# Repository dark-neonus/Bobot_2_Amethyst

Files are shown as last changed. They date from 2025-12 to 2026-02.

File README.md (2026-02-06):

# Bobot_2_Amethyst
Second robot from Bobot series of robots. A huge amount of things in this robot address problems of previous Bobot.

## Table of Contents

- [Features](#features)
  - [Mechanical](#mechanical)
    - [Handle](#handle)
    - [Back Buttons](#back-buttons)
    - [Power Switch](#power-switch)
    - [Screwdriver With Built In Case](#screwdriver-with-built-in-case)
    - [Access panel](#access-panel)
  - [Hardware](#hardware)
    - [Shortcut Components List](#shortcut-components-list)
    - [ESP32 Microcontroller](#esp32-microcontroller)
    - [2.42 Inch OLED I2C Display](#242-inch-oled-i2c-display)
    - [MAX98357A Audio Module](#max98357a-audio-module)
    - [Li-Po 3000mAh 3.7V Battery 1S2P](#li-po-3000mah-37v-battery-1s2p)
    - [BQ25895 Battery Management Module](#bq25895-battery-management-module)
    - [Button Board Based On MCP23017 I/O Expander](#button-board-based-on-mcp23017-io-expander)
    - [Touch Board Based On MPR121QR2 Touch Controller](#touch-board-based-on-mpr121qr2-touch-controller)
  - [Software](#software)
    - [Assets](#assets)
    - [Developer Tools](#developer-tools)
    - [Graphic Engine](#graphic-engine)

# Features 

## Mechanical

### Handle

#### Description

On the top there is the handle which is hidden in base.
It rotates out on bearings.
Rotation is locked by mechanism on top of base.

### Back Buttons

#### Description

On the back there are 9 buttons to interact with bobot.
They are with 3d printed tops with symbols representing purpose.

Buttons:
```
 _________________________________
|    Back    |  Up  |     UI      |
|____________|______|_____________|
|    Left    |  OK  |    Right    |
|____________|______|_____________|
|  Settings  | Down |    Debug    |
|____________|______|_____________|
```

### Power Switch

#### Description

At the bottom of left side of bobot(looking at their face) there is power switch, which is connect batteries to power regulation module.

### Screwdriver With Built In Case

#### Description

At the left side of bobot there is case with screwdriver which can unscrew all screws in bobot.
It is based on push latch mechanism, to be held inside of bobot.

### Access panel

#### Description

At the right side there is panel on 2 screws which give access to main microcontroller esp32 dev kit board. When this panel taken apart, esp32 can be fully removed from socket and access to micro sd is revealed.

## Hardware

### Shortcut Components List

| Component | Quantity| Description | Datasheet | Store |
|---|---|---|---|---|
|ESP32 unnamed DevKit board|1|Microcontroller|-|-|
|BQ25895 | 1 | power managment ic | [datasheet](https://www.ti.com/lit/ds/symlink/bq25895.pdf) | [store](https://www.aliexpress.com/item/1005008068013158.html) |
| MCP23017 | 1 | 16-Bit I/O Expander with Serial Interface(16 parallel pins to I2C) | [datasheet](https://ww1.microchip.com/downloads/en/devicedoc/20001952c.pdf) | [store](https://www.aliexpress.com/item/1005006974304942.html) |
| MPR121QR2  | 1 | 12 touch buttons driver with I2C interface | [datasheet](https://files.seeedstudio.com/wiki/Grove-I2C_Touch_Sensor/res/Freescale_Semiconductor;MPR121QR2.pdf) | [store](https://www.aliexpress.com/item/1005006944721047.html) |
| TL2285OA  | 9 | Push latch button without fixation | [datasheet](https://www.alldatasheet.com/html-pdf/437236/E-SWITCH/TL2285OA/385/1/TL2285OA.html) | [store](https://www.aliexpress.com/item/1005006775951751.html) |
| MAX98357A | 2 | Chip for audio output: DAC + amplifier in one chip | [datasheet](https://www.analog.com/media/en/technical-documentation/data-sheets/max98357a-max98357b.pdf) | [store](https://www.aliexpress.com/item/1005010444800168.html) |
| BMI160 | 1 | Sensor gyroscope + accelerometer 6DOF | - | [store](https://www.aliexpress.com/item/1005009421405155.html) |

| Component | Quantity| Store |
|---|---|---|
|Resistor 150Ω|1|[store](https://www.aliexpress.com/item/1005008789698065.html)|
|Resistor 4.7kΩ|6|[store](https://www.aliexpress.com/item/1005008789698065.html)|
|Resistor 5.1kΩ|1|[store](https://www.aliexpress.com/item/1005008789698065.html)|
|Resistor 10kΩ|18|[store](https://www.aliexpress.com/item/1005008789698065.html)|
|Resistor 33kΩ|1|[store](https://www.aliexpress.com/item/1005008789698065.html)|
|Resistor 75kΩ|1|[store](https://www.aliexpress.com/item/1005008789698065.html)|
|Capacitor 47nF|1|[store](https://www.aliexpress.com/item/1005010516436707.html)|
|Capacitor 100nF|2|[store](https://www.aliexpress.com/item/1005010516436707.html)|
|Capacitor 1uF|10|[store](https://www.aliexpress.com/item/1005010516436707.html)|
|Capacitor 4.7uF|1|[store](https://www.aliexpress.com/item/1005010516436707.html)|
|Capacitor 10uF|4|[store](https://www.aliexpress.com/item/1005010516436707.html)|
|Inductor 2.2uH|1|[store](https://www.aliexpress.com/item/1005001699576419.html)|
|Thermistor B3435 MF52D 10K|1|[store](https://www.aliexpress.com/item/1005006804356266.html)|

### ESP32 Microcontroller

#### Description

Main microcontroller will be unnamed clone of esp32 wroom dev kit with `30 pins`.
It will be placed in sockets on pcb on right side of bobot.

#### Links

[Overview](https://www.espboards.dev/esp32/esp32-30pin-devkit-generic/)

[Datasheet](https://documentation.espressif.com/esp32_datasheet_en.pdf)

[Technical Reference Manual](http://documentation.espressif.com/esp32_technical_reference_manual_en.pdf)

### 2.42 Inch OLED I2C Display

#### Description

There is 2.42 inch OLED display in front side of bobot.
Esp32 communicate with display using `i2c` protocol on
esp32 dedicated i2c pins. This display use SSD1309 driver.

#### Pinout

| Pin / Signal | Source / Connection | GPIO / Net | Description |
|---|---|---|---|
| SDA | ESP32 | GPIO21 | I²C data line (main I²C bus) |
| SCL | ESP32 | GPIO22 | I²C clock line (main I²C bus) |

#### Links

[General information](https://turkish.chenghaolcd.com/doc/44205281/2-42-oled-display-module-ic-i2c-spi-serial-with-ssd1309-controller.pdf)

### MAX98357A Audio Module

#### Description

Bobot uses two MAX98357A modules for stereo audio output. Each module integrates a DAC and Class D amplifier. One module is strapped for left channel, the other for right channel. The modules communicate with ESP32 via shared I2S bus.

#### Configurations

Hardware:

1. Left channel module: GAIN <mark>CONNECTION_TBD</mark> and <span style="text-decoration:overline">SD_MODE</span> strapped to VCC for left channel output
2. Right channel module: GAIN <mark>CONNECTION_TBD</mark> and <span style="text-decoration:overline">SD_MODE</span> strapped to GND for right channel output
3. Both modules share common I2S data and clock lines
4. 1 µF decoupling capacitor between VDD and GND for each module

Software:

1. Configure ESP32 I2S peripheral in stereo mode
2. Set sample rate to <mark>SAMPLE_RATE_TBD</mark> and bit depth to <mark>BIT_DEPTH_TBD</mark>

#### Pinout

| Pin / Signal | Connection | Net / GPIO | Description |
|---|---|---|---|
| LRC (LRCLK) | ESP32 | GPIO27 | I²S word select (left/right clock); shared between both modules. |
| BCLK | ESP32 | GPIO26 | I²S bit clock; shared between both modules. |
| DIN | ESP32 | GPIO25 | I²S serial data input; shared between both modules. |
| GAIN | Configured per module | — | Gain setting pin; sets output gain. |
| <span style="text-decoration:overline">SD_MODE</span> | Configured per module | — | Channel select: left or right. |
| VDD | 3.3V | 3.3V | Power supply (2.5-5.5V); 1 µF decoupling to GND. |
| GND | Ground | GND | Ground. |

#### Links

[Datasheet](https://www.analog.com/media/en/technical-documentation/data-sheets/max98357a-max98357b.pdf)

### Li-Po 3000mAh 3.7V Battery 1S2P

#### Description

There are two parallely connecteed li-po battery in bobot, which in total give 6000mAh battery capacity.

#### Links

[Buy](https://prom.ua/ua/p2843472521-litij-polimernyj-akkumulyator.html)

### BQ25895 Battery Management Module

#### Description

Bobot have power management module, which will consist of: 
- `BQ25895` I2C Controlled Single Cell 5-A Fast Charger with MaxChargeTM for High Input
Voltage and Adjustable Voltage 3.1-A Boost Operation
- Thermistor as BQ25895 requires placed onto battery with
  RTHcold = 27 kΩ at 0 °C
  and RTHhot = 4.9 kΩ at 45 °C values
- Led to indicate charge status
- Connection to esp32 I2C bus and INT pin support

And will do:
- Active conversation with Esp32 with transfering measurements of voltages and current(battery monitor feature)

#### Configurations

Hardware:

1. CE pin tied to GND to enable charging
2. Using resistors RT1=5.1 kΩ and RT2=33 kΩ to make BQ25895 read thermistor values correct
3. Led going from SYS to STAT through 2.2kΩ resistor
4. Connecting ILIM pin to GND through Rilim=150 Ω resistor. Calculated using formula from datasheet at section 8.2.12. 150 Ω resistor limit input current to ~2.6A.
5. OTG pin connected to GND to disable boost mode activation

Software:

1. Set register CONV_RATE to 1 to enable active conversation between BQ25895 and ESP32
2. <mark>Set register IINLIM to value representing \<DESIRED_INPUT_CURRENT>
3. <mark>Set TREG to \<DESIRED_MAXIMAL_IC_TEMPERATURE> to regulate at which temperature BQ25895 will lower down charging current

#### Pinout

| Pin / Signal | Connection | Net / GPIO | Description |
|---|---|---|---|
| SDA | ESP32 | GPIO21 | I²C data line for charger configuration/monitoring. |
| SCL | ESP32 | GPIO22 | I²C clock line for charger configuration/monitoring. |
| INT | ESP32 | GPIO (TBD) | Open-drain interrupt (active-low) for charge/fault events; 10 kΩ pull-up to 3.3 V. |
| VBUS | USB Type-C port | VBUS | Charger input supply (3.9–14 V). Decouple close to pin. |
| D+ | USB only | Connect only to USB connector | Used internally for BC1.2/MaxCharge detection. |
| D− | USB only | Connect only to USB connector | Same as D+. |
| STAT | Status LED | — | Open-drain charge status output; LED + resistor to 3.3 V. |
| TS | NTC divider | NTC | Battery temperature sense via NTC near battery; safety-critical. |
| BAT | Battery pack | BAT+ | Battery positive terminal (1S Li-ion/Li-poly). |
| SYS | System rail | SYS | Managed system supply; feeds 3.3 V regulator for ESP32. |
| PGND | Power ground | GND | High-current ground return for charger, battery, SYS, PMID caps. |
| CE | GND | — | Charge enable (active-low); tied to GND for always-enabled charging. |
| ILIM | Resistor → GND | R_ILIM | Hardware input-current limit set to ~3 A (protects USB source). |
| SW | Inductor | SW | Switching node to inductor (keep short, noisy). |
| BTST | Bootstrap cap | BTST | Bootstrap capacitor to SW for high-side gate drive. |
| REGN | Decoupling cap | REGN | Internal LDO output; bias rail (decouple to GND). |
| EPAD (PowerPAD) | PCB copper | PGND | Thermal + electrical ground; must be soldered to PGND with vias. | 
| OTG | Disabled | Tie to GND | Prevents boost (OTG) mode activation. |
| PMID | Not exported | Local ceramic caps to PGND only (≥8.2 µF) | Do not power loads; keep short return. |
| QON | Unused | Leave unconnected | Internal pull-up keeps default behavior. |
| DSEL | Unused | Leave unconnected | Not needed without external USB data switch. |

### Button Board Based On MCP23017 I/O Expander

#### Description

The MCP23017 is a 16-bit I/O expander used to interface with the 9 back panel buttons. It communicates with the ESP32 via I2C at address <mark>I2C_ADDRESS_TBD</mark>. The device provides interrupt-on-change functionality through its INTA and INTB pins, allowing the ESP32 to detect button presses efficiently without constant polling.

Buttons:
```
 _________________________________
|    Back    |  Up  |     UI      |
|____________|______|_____________|
|    Left    |  OK  |    Right    |
|____________|______|_____________|
|  Settings  | Down |    Debug    |
|____________|______|_____________|
```

#### Configurations

Hardware:

1. I2C address set via A0, A1, A2 pins: <mark>ADDRESS_CONFIG_TBD</mark>
2. INTA and INTB pins pulled up to 3.3V through 4.7 kΩ resistors
3. NOT RESET pin tied to 3.3V to keep device enabled
4. Each button input uses a low-pass filter with:
   - 10 kΩ pull-up resistor to 3.3V (default state: logic HIGH)
   - 10 kΩ series resistor between button and IC pin
   - 1 µF capacitor to GND for debouncing
5. Buttons are in high-Z state (disconnected) by default, connect to GND when pressed (active-low)

Software:

1. Configure GPA0-GPA7 and GPB0 as inputs with interrupt-on-change enabled
2. Set up interrupt polarity and configure interrupt mirroring if needed

#### Pinout

| Pin / Signal | Connection | Net / GPIO | Description |
|---|---|---|---|
| SDA | ESP32 | GPIO21 | I²C data line (shared with display and BMS). |
| SCL | ESP32 | GPIO22 | I²C clock line (shared with display and BMS). |
| INTA | ESP32 | <mark>GPIO (TBD)</mark> | Interrupt output for Port A changes; 4.7 kΩ pull-up to 3.3V. |
| INTB | ESP32 | <mark>GPIO (TBD)</mark> | Interrupt output for Port B changes; 4.7 kΩ pull-up to 3.3V. |
| RESET | 3.3V | — | Active-low reset; tied to 3.3V to keep device enabled. |
| A0 | <mark>TBD</mark> | — | I²C address bit 0. |
| A1 | <mark>TBD</mark> | — | I²C address bit 1. |
| A2 | <mark>TBD</mark> | — | I²C address bit 2. |
| GPA0 | BTN_BACK | — | Back button input (filtered, active-low). |
| GPA1 | BTN_TOP | — | Up button input (filtered, active-low). |
| GPA2 | BTN_UI | — | UI button input (filtered, active-low). |
| GPA3 | BTN_LEFT | — | Left button input (filtered, active-low). |
| GPA4 | BTN_OK | — | OK button input (filtered, active-low). |
| GPA5 | BTN_RIGHT | — | Right button input (filtered, active-low). |
| GPA6 | BTN_SETTINGS | — | Settings button input (filtered, active-low). |
| GPA7 | BTN_DOWN | — | Down button input (filtered, active-low). |
| GPB0 | BTN_DBG | — | Debug button input (filtered, active-low). |
| GPB1-GPB7 | Unused | — | Available for future expansion. |
| VSS | GND | GND | Ground. |
| VDD | 3.3V | 3.3V | Power supply (1.8-5.5V). |

### Touch Board Based On MPR121QR2 Touch Controller

#### Description

The MPR121QR2 is a 12-channel capacitive touch sensor controller used to implement a touch-sensitive electrode matrix. It communicates with the ESP32 via I2C at address <mark>I2C_ADDRESS_TBD</mark>. The device provides interrupt functionality through its NOT IRQ pin, allowing the ESP32 to detect touch events efficiently.

The electrode matrix follows the design from [NXP Application Note AN4600](https://www.nxp.com/docs/en/application-note/AN4600.pdf), where touch detection is achieved by the intersection of X and Y electrodes:
- ELE0-ELE6 correspond to X0-X6 positions (7 columns)
- ELE7-ELE11 correspond to Y0-Y4 positions (5 rows)

Touch coordinates are determined by the intersection of active XN and YM electrodes.

#### Configurations

Hardware:

1. I2C address set via ADD pin: <mark>ADDRESS_CONFIG_TBD</mark>
2. NOT IRQ pin pulled up to 3.3V through 4.7 kΩ resistor
3. REXT pin pulled down through 75 kΩ resistor to GND
4. 0.1 µF decoupling capacitor between VDD and VSS
5. 0.1 µF capacitor between VREG and GND for internal regulator stability
6. PCB electrode layout follows AN4600 routing guidelines
7. Electrode pad size: 5 mm × 5 mm (increased from AN4600's 3.5-4 mm recommendation)

Software:

1. <mark>Configure touch and release thresholds for each electrode</mark>
2. <mark>Enable electrode matrix scanning mode according to AN4600</mark>
3. <mark>Implement touch coordinate decoding from electrode intersections</mark>

#### Pinout

| Pin / Signal | Connection | Net / GPIO | Description |
|---|---|---|---|
| SDA | ESP32 | GPIO21 | I²C data line (shared with display, BMS, and button board). |
| SCL | ESP32 | GPIO22 | I²C clock line (shared with display, BMS, and button board). |
| IRQ | ESP32 | <mark>GPIO (TBD)</mark> | Active-low interrupt output for touch events; 4.7 kΩ pull-up to 3.3V. |
| ADD | <mark>TBD</mark> | — | I²C address selection pin. |
| ELE0 | Touch electrode | X0 | Electrode column 0. |
| ELE1 | Touch electrode | X1 | Electrode column 1. |
| ELE2 | Touch electrode | X2 | Electrode column 2. |
| ELE3 | Touch electrode | X3 | Electrode column 3. |
| ELE4 | Touch electrode | X4 | Electrode column 4. |
| ELE5 | Touch electrode | X5 | Electrode column 5. |
| ELE6 | Touch electrode | X6 | Electrode column 6. |
| ELE7 | Touch electrode | Y0 | Electrode row 0. |
| ELE8 | Touch electrode | Y1 | Electrode row 1. |
| ELE9 | Touch electrode | Y2 | Electrode row 2. |
| ELE10 | Touch electrode | Y3 | Electrode row 3. |
| ELE11 | Touch electrode | Y4 | Electrode row 4. |
| REXT | 75 kΩ → GND | — | External resistor for charge current setting. |
| VREG | 0.1 µF cap → GND | — | Internal regulator output; decoupled to GND. |
| VSS | GND | GND | Ground. |
| VDD | 3.3V | 3.3V | Power supply (1.71-3.6V); 0.1 µF decoupling to GND. |

#### Links

[Application Note AN4600 - MPR121 Proximity Sensing](https://www.nxp.com/docs/en/application-note/AN4600.pdf)

## Software

### Assets

#### Description

There will be 4 main face assets libraries(profiles) where each of them can be set as source library, single library with faces not
connected to any library and few non-main libraries which
may be added in future for Bobot:

1. Classic - face library of first Bobot with possible extensions for new features
2. Amethyst - face library for current model which will stick to classic expressions but with fresh look
3. Cutie - face library consisting of cute assets with cat-like features and big eyes
4. Doodles - face library consisting of weirdly paint assets representing scratch style
4. Other - library with face expressions not connected to any full library, cannot be set as source library

#### Structure

##### Expression

Expression - elementary unit of Bobot expressions graphic. It is directory with graphic assets of expression nd file with expression description and metadata. Expression can be set as temporally Bobot face in mode with manual expression selection.

Expression strucutre:

```
Expression
├── Description.ini
├── Frames
│   ├── Frame_00.bin
│   ├── Frame_01.bin
│   ├──...
│   ├── Frame_N.bin
```

Frame binary format:
Each frame file is binary file with monochrome bitmap data optimized for u8g2 library. Frame dimensions are stored in Description.ini to reduce file size and improve loading speed. Format structure: monochrome bitmap data where each byte represents 8 vertical pixels organized in column-major order. During runtime dimensions are read once from Description.ini, then frames are read from SD card and passed directly to u8g2 display functions.

Expression `Description.ini`:
```ini
; Description for Expression_Name expression

[Loop]
; Supported Loop types:
;
; 1. IdleBlink(default) - Display first frame for random time in range
;                           [IdleTimeMinMS, IdleTimeMaxMS] ms and after that
;                           run animation with AnimationFPS fps.
;                           After that switch frame to first and repeat.
;
; 2. Loop - Repeat animation from first frame to last with AnimationFPS fps.
;           IdleTimeMinMS and IdleTimeMaxMS are unnecessary and wiil be ignored
;           if presented
;
; 3. Image - Display only first frame. All fields except type are unnecessary 
;             and wiil be ignored if presented

; Type field must be first
Type = IdleBlink ; default = IdleBlink
AnimationFPS = 20 ; default = 20
IdleTimeMinMS = 1000 ; default = 1000
IdleTimeMaxMS = 1000 ; default = 1000

[Dimensions]
; Frame dimensions (auto-filled by export tool)
Width = 128
Height = 64
```

##### Library
Library - list of expressions. Some libraries can be sourced to be used as Bobot faces for corresponding events. Library consist of file with library description, information and metadata, directory with expressions and file with behaviour and mapping(if needed) expressions in expressions directory to Bobots events. If there is no behaviour and mapping file, library cant be sourced.
```
Library
├── Description.ini
├── Behaviour.csv
├── Expressions
│   ├── Expression_A
│   ├── Expression_B
│   ├──...
│   ├── Expression_Z
```

### Developer Tools

#### Graphics Structure Generation Script
Script is placed in `devtools` directory under project root. It consists of two files: `generate_graphics_structure.py` with main logic and `generate_graphics.sh` shell wrapper for convenient execution. Script can be run with `./devtools/generate_graphics.sh` from project root.

Script reads `assets/graphics/Description.ini` and processes all libraries marked as `true`. For each enabled library it creates directory structure in `assets/graphics/libraries/LibraryName` if not exists. Then it iterates over all directories inside library which are expressions. For each expression it generates default `Description.ini` if not present.

For expressions containing `.aseprite` or `.ase` files script uses aseprite in batch mode to export animation frames as PNG sequence into temporary directory. Then it converts each PNG frame to u8g2-compatible binary format and saves as `Frame_XX.bin` files in expression `Frames` subdirectory. After conversion all temporary PNG files are deleted. If `Frames` directory exists from previous run it is completely cleared before generating new frames to avoid stale data.

Aseprite is built from source during Docker container setup and available at `/usr/local/bin/aseprite`. Script automatically finds aseprite executable and falls back gracefully if not available.

#### SD Card Assets Update Script
**WARNING: Currently this feature is broken and dont work properly**

##### ESP32 Side
ESP32 can enter asset upload mode when requested, hosting a simple HTTP server on WiFi. In main microcontroller loop it checks for button combination or serial command to activate upload mode. When activated, ESP32:
- Stops regular operating mode
- Starts HTTP server on port 8080
- Waits for upload requests

Upload process:
1. HTTP POST to `/start` - ESP32 deletes entire `/assets` directory (preserving other files/directories)
2. HTTP POST to `/file` - Upload individual files with path in request
3. HTTP POST to `/complete` - Finalize upload and return to normal mode

The `/assets` directory is completely cleared at start of upload, but other directories and files on SD card remain untouched. Upload mode cannot be interrupted except by system-level events.

##### Host (PC) Side
Host PC connects to ESP32 via WiFi to upload assets. In `devtools` directory there are `flash_micro_sd.sh` and `flash_micro_sd.py` scripts:

**Shell script (`flash_micro_sd.sh`)**:
- Manages directory navigation
- Configures Python environment
- Provides simple interface: `./devtools/flash_micro_sd.sh`

**Python script (`flash_micro_sd.py`)**:
- Discovers ESP32 on network (mDNS or manual IP)
- Sends `/start` command and waits for confirmation
- Uploads entire `assets` directory via HTTP POST (excludes .aseprite files)
- Sends `/complete` command when done
- Displays progress and handles errors

Usage:
```bash
# From project root
./devtools/flash_micro_sd.sh

# Or with custom IP
./devtools/flash_micro_sd.sh --ip 192.168.1.100
```

The upload is reliable (checksums verified), fast (WiFi bandwidth), and doesn't interfere with USB console/debugging.

### Servo Control

Bobot uses PCA9685 16-channel PWM driver (default I2C address 0x40) to control servo motors for legs. Driver supports up to 16 servos with angle control from 0 to 180 degrees. On startup all servos are initialized to 90 degrees center position.

A servo control UI mode is available for testing and calibration. Mode is accessed by cycling through UI modes with UI button. In servo mode:
- LEFT/RIGHT buttons switch between channels 0-15
- UP/DOWN buttons adjust selected servo angle in 5-degree increments
- Display shows current channel and angle

### Graphic Engine

#### Position class Vec2i

Class which will hold two integer values x and y and whcih will be used for working with position values.
This class will have implementation of basic operaions: addition, substraction, multiplicating, their with assignment analogues(e.g. plus equal) and negative sign.
Also it will have functions which will return string that represents vector data.
This class will be used to hold values like positions, offset, speed, etc.

#### Frame class

Simple class which will hold only bitmap value of frame in format which will be place-and-go for u8g2 function to draw bitmap on screen and frame size.
Class will have function to build object from raw file data, received from storage through DMA.

#### Expression class

Class which will hold sequence of frames, current frame index, fps and data about correct playback way of animation.
This class will have functions to draw current frame on given display with given offset, increment frame index, set frame index, update function which will handle correct index incrementation depended on animation loop type.
Also there will be function to create animation object(which will do subcalls of constructing frames from files) from given directory

#### Future functional
For now this code is just to test code on development setup to understand that prom not in code, when test will be runned on manufactured pcb's. They wont be implemented right now for time saving and simplisity.
Future functional may include, but not limited to:

1) Expression Library class which will handle mapping events/states to storage directories and will handle dynamic load of expression on event/state switch(to not hold full expressions library in memory). Also this class can handle graphic profiles switch.

2) Upgrading Expression class functions to work correct in energy efficient code, including handling fps using timer interrupts, to set esp32 to sleep mode for as long as possible.

3) Profile class which will be placeholder for data about each library possibilities, storage path and names.

4) Classes for text, side menu, burger menu, navigation system visualizations, regular bitmaps drawings, and possibly more.

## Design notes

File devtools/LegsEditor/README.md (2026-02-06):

# Bobot Legs Editor

A lightweight, fast, and modular Python-based visual editor for designing gait patterns (animations) for a 4-legged spider robot.

## Features

- **3D Visualization**: Real-time 3D rendering of the robot with forward kinematics
- **Interactive Timeline**: Visual keyframe editor with drag-and-drop support
- **Properties Panel**: Intuitive sliders for controlling servo angles (0-180°)
- **Playback Engine**: Play, pause, loop animations with smooth interpolation
- **Save/Load**: Export and import animations as JSON files
- **Camera Controls**: Fusion 360-style camera (orbit, pan, zoom)

## Installation

1. Install Python 3.10 or higher
2. Install system dependencies (for dev containers/headless environments):

```bash
# Debian/Ubuntu
apt-get update && apt-get install -y xvfb

# The application will automatically use Xvfb for headless rendering
```

3. Install Python dependencies:

```bash
pip install -r requirements.txt
```

## Usage

Run the application:

```bash
python main.py
```

The application automatically handles X11 display setup:
- ✅ Detects if X display is available
- ✅ Auto-starts Xvfb virtual framebuffer if needed
- ✅ Works in dev containers, SSH sessions, and headless environments
- ✅ Cleans up resources on exit

**Viewing the GUI (from dev container/Windows):**

Xvfb is virtual (headless) by default. To see the actual window:

```bash
# Start VNC server
./start_vnc_tiger.sh

# Then open in browser: http://localhost:6080/vnc.html
# Click "Connect" and run in another terminal:
export DISPLAY=:99
python main.py
```

**Testing the display fix:**
```bash
python test_display_fix.py
```

### Controls

#### 3D Viewport
- **Orbit**: `Shift` + `Middle Mouse Drag`
- **Pan**: `Middle Mouse Drag`
- **Zoom**: `Mouse Wheel`

#### Timeline
- **Scrub**: Click on time ruler to jump to that time
- **Add Keyframe**: Click "+ Keyframe" button
- **Play/Pause**: Click play button or press `Space`
- **Zoom Timeline**: `Ctrl` + `Mouse Wheel`
- **Scroll Timeline**: `Mouse Wheel`

#### Keyboard Shortcuts
- `Ctrl+N`: New animation
- `Ctrl+O`: Open animation
- `Ctrl+S`: Save animation
- `Ctrl+Shift+S`: Save As
- `Space`: Play/Pause

## File Format

Animations are saved as JSON files with the following structure:

```json
{
  "meta": {
    "duration_sec": 5.0,
    "loop": true
  },
  "keyframes": [
    {
      "time": 0.0,
      "servos": {
        "leg0_j1": 90,
        "leg0_j2": 90,
        "leg0_j3": 90,
        ...
      }
    }
  ]
}
```

## Robot Configuration

The robot's physical dimensions and joint constraints are defined in `resources/robot_config.json`:

- **Body**: 120mm x 120mm x 40mm
- **Legs**: 4 legs with 3 joints each
  - Coxa: 40mm (horizontal rotation)
  - Femur: 80mm (vertical rotation)
  - Tibia: 120mm (vertical rotation)

## Project Structure

```
LegsEditor/
├── main.py                 # Application entry point
├── config_loader.py        # Robot configuration loader
├── state_manager.py        # Application state management
├── core/
│   ├── kinematics.py       # Forward kinematics calculations
│   └── playback.py         # Animation playback engine
├── gui/
│   ├── viewport.py         # 3D rendering (ModernGL)
│   ├── timeline.py         # Timeline panel (ImGui)
│   ├── properties.py       # Properties panel (ImGui)
│   └── utils.py            # Camera and helper functions
└── resources/
    └── robot_config.json   # Robot physical configuration
```

## Technology Stack

- **GUI**: imgui-bundle (Dear ImGui + Hello ImGui)
- **3D Rendering**: ModernGL
- **Math**: NumPy, PyGLM
- **Language**: Python 3.10+

## Development

This project follows a "vibecoding" approach - prioritizing rapid iteration, minimal boilerplate, and high interactivity.

## Troubleshooting

### GLFW Error: Failed to open display

**Error:**
```
Glfw Error 65544: X11: Failed to open display :4
RuntimeError: IM_ASSERT( glfwInitSuccess )
```

**Solution:**
This error occurs when no X server is available. The application now automatically handles this by starting Xvfb. If you still encounter issues:

1. Ensure Xvfb is installed:
   ```bash
   apt-get install xvfb
   ```

2. Check the logs in `logs.md` for detailed troubleshooting steps

3. Verify the fix is working:
   ```bash
   python test_display_fix.py
   ```

### OpenGL Rendering Errors

If you see `GL_INVALID_VALUE` errors, these are separate from the GLFW initialization and indicate issues in the viewport rendering code (`gui/viewport.py`). The application should still run despite these warnings.

## License

See LICENSE file in the project root.

## Credits

Created for the Bobot 2 Amethyst spider robot project.

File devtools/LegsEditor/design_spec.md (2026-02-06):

Here is the comprehensive design document (`design_spec.md`) that you can feed into another AI session (or use yourself) to build the application. It covers every aspect of the logic, UI, and architecture without ambiguity.

Image that shows desirable gui look(schematically, without colors and styles):

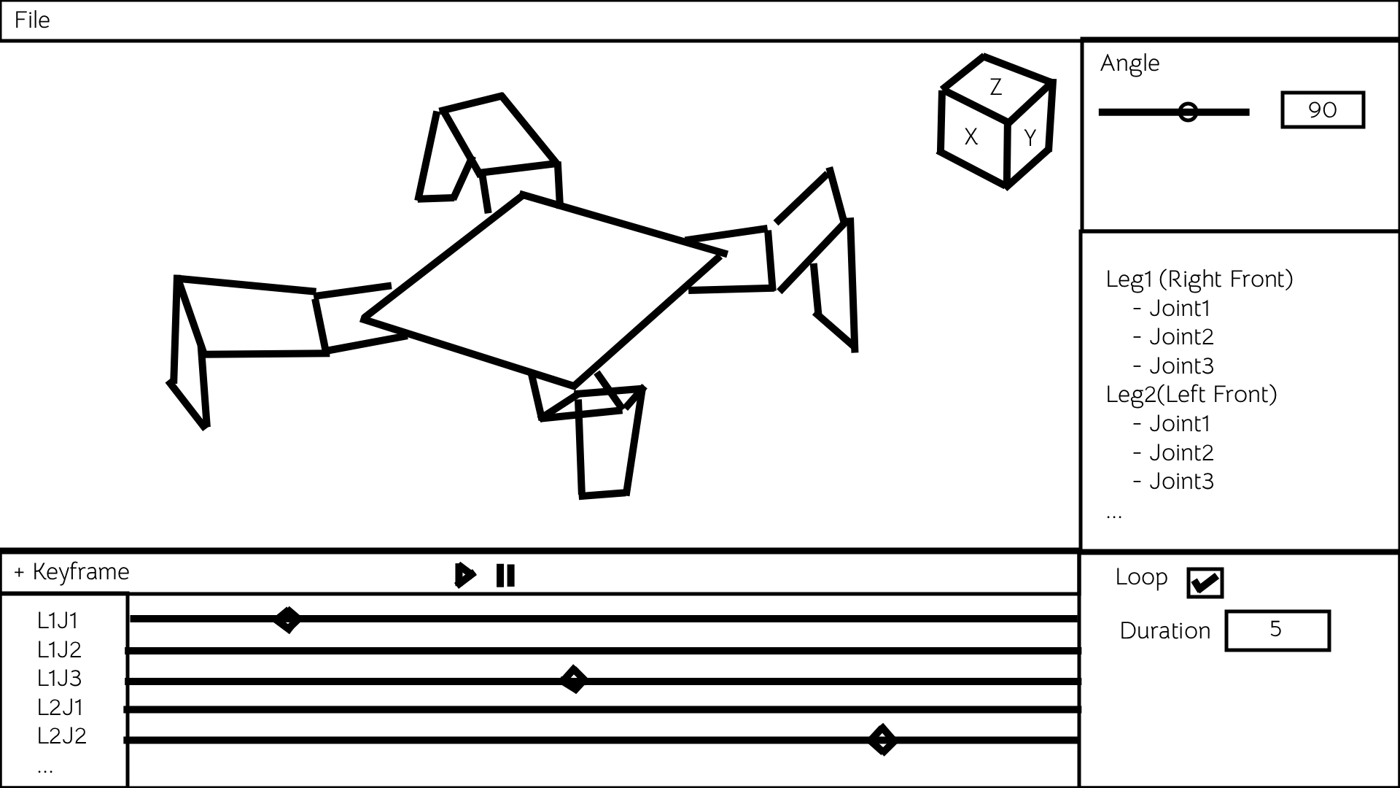
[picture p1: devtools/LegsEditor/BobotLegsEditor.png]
GuiScheme


---

# Technical Design Specification: Spider Robot Gait Editor

## 1. Project Overview

**Goal:** Create a lightweight, fast, and modular Python-based visual editor for designing gait patterns (animations) for a 4-legged spider robot.
**Core Function:** Users can visualize the robot in 3D, manipulate servo angles via sliders or 3D selection, place keyframes on a timeline, and export the resulting animation to JSON.
**Target Workflow:** "Vibecoding" — prioritizing rapid iteration, minimal boilerplate, and high interactivity.

---

## 2. Technology Stack

### Core Frameworks

* **Language:** Python 3.10+
* **GUI & Windowing:** `imgui_bundle`
* *Why:* Contains **Dear ImGui** (UI), **Hello ImGui** (Window/Context management), and **ImGuizmo** (3D View Cube & Gizmos) in a single pip install. It supports docking and fast rendering.

* **3D Rendering:** `ModernGL` (over raw PyOpenGL)
* *Why:* Pythonic wrapper for OpenGL. Easier to manage shaders, Vertex Buffer Objects (VBOs), and Framebuffers for the "Render-to-Texture" view.

* **Math:** `numpy` and `pyglm`
* *Why:* `numpy` for array manipulation; `pyglm` for OpenGL-compatible Matrix/Vector math (Projection, View, Model matrices).

### Dependencies

* `imgui-bundle`
* `moderngl`
* `numpy`
* `pyglm` (or `scipy.spatial.transform` if preferred, but glm is standard for graphics)

---

## 3. Data Architecture

### 3.1 Robot Configuration (`robot_config.json`)

Stores the physical dimensions and mechanical constraints. This file is read-only during the session.

```json
{
  "body": {
    "length_mm": 120.0,
    "width_mm": 120.0,
    "height_mm": 40.0
  },
  "legs": {
    "count": 4,
    "mounting_points": [
      {"id": 0, "name": "FrontRight", "x": 60, "y": 60, "z": 0, "base_rotation": 45},
      {"id": 1, "name": "BackRight", "x": -60, "y": 60, "z": 0, "base_rotation": 135},
      {"id": 2, "name": "BackLeft", "x": -60, "y": -60, "z": 0, "base_rotation": 225},
      {"id": 3, "name": "FrontLeft", "x": 60, "y": -60, "z": 0, "base_rotation": 315}
    ],
    "segments": {
      "coxa_len_mm": 40.0,   // Joint 1 -> Joint 2
      "femur_len_mm": 80.0,  // Joint 2 -> Joint 3
      "tibia_len_mm": 120.0  // Joint 3 -> Tip
    },
    "joints": [
      {"id": 1, "name": "Coxa", "axis": "z", "min": 0, "max": 180},  // Horizontal rotation
      {"id": 2, "name": "Femur", "axis": "y", "min": 0, "max": 180}, // Vertical rotation
      {"id": 3, "name": "Tibia", "axis": "y", "min": 0, "max": 180}  // Vertical rotation
    ]
  }
}

```

### 3.2 Animation Project (`animation.json`)

Stores the timeline data.

```json
{
  "meta": {
    "duration_sec": 5.0,
    "loop": true
  },
  "keyframes": [
    {
      "time": 0.0,
      "servos": {
        "leg0_j1": 90, "leg0_j2": 90, "leg0_j3": 90,
        "leg1_j1": 90, "leg1_j2": 90, "leg1_j3": 90,
        "..." : "..."
      }
    },
    {
      "time": 1.5,
      "servos": {
        "leg0_j1": 45, "..." : "..."
      }
    }
  ]
}

```

---

## 4. Application Logic & Modules

### 4.1 Forward Kinematics (FK)

The app must convert servo angles (0-180) into 3D coordinates to draw the skeleton.

* **Coordinate System:** Z-Up (standard for robotics) or Y-Up (standard for OpenGL). *Decision: Y-Up for OpenGL ease, convert Z-Up data on load.*
* **Calculation Chain (per leg):**
1. Start at `Body Center (0,0,0)`.
2. Translate to `Mounting Point`.
3. Rotate by `Base Rotation` (leg corner angle).
4. **Joint 1 (Coxa):** Rotate around local UP axis (horizontal). Translate `coxa_len`.
5. **Joint 2 (Femur):** Rotate around local RIGHT axis (vertical). Translate `femur_len`.
6. **Joint 3 (Tibia):** Rotate around local RIGHT axis. Translate `tibia_len`.

### 4.2 Playback Engine

* **State:** Holds `current_time` (float).
* **Logic:**
* If `playing == True`: Increment `current_time` by `delta_time`.
* **Loop Handling:** If `current_time > duration`:
* If `loop == True`: `current_time = 0`.
* If `loop == False`: `current_time = duration`; `playing = False`.

* **Interpolation:**
* Find two keyframes surrounding `current_time` (Key A and Key B).
* Calculate factor `t = (current_time - A.time) / (B.time - A.time)`.
* `CurrentAngle = Lerp(A.angle, B.angle, t)`.
* Update the FK model with `CurrentAngle`.

---

## 5. Graphical User Interface (GUI) Layout

The layout uses ImGui Docking.

### 5.1 Main Menu Bar

* **File:**
* `New`: Clears keyframes, resets duration.
* `Open`: Loads JSON into state.
* `Save`: Overwrites current file.
* `Save As...`: Opens file dialog to save JSON.

* **View:** Toggle visibility of panels.

### 5.2 The 3D Viewport Window

A dedicated ImGui window acting as a container for the OpenGL framebuffer.

* **Visuals:**
* Grid floor on XZ plane.
* Robot Body (Box).
* Leg Segments (Lines or Cylinders).
* Joints (Spheres or small Cubes).

* **Controls (Fusion 360 Style):**
* **Orbit:** `Shift` + `Middle Mouse Drag`.
* **Pan:** `Middle Mouse Drag`.
* **Zoom:** `Mouse Wheel`.
* **Selection:** `Left Click` on a joint highlights it and selects the corresponding track in Timeline/Properties.

* **Overlays:**
* **View Cube:** (Top Right) Click faces to snap to Front/Top/Right views (provided by `ImGuizmo`).

### 5.3 The Properties Panel (Right Side)

Shows controls for the currently selected context.

* **Global Section:**
* Slider: `Global Speed` (optional).

* **Leg Control Section:**
* List of Legs (collapsible headers).
* Inside Leg: Sliders for J1, J2, J3.
* *Interaction:* Dragging these sliders updates the "Current Pose" (and modifies the active Keyframe if the playhead is exactly on a keyframe).

### 5.4 The Timeline Panel (Bottom)

* **Header Controls:**
* Button: `Add Keyframe` (Inserts keyframe at current cursor pos with current pose).
* Button: `Play` / `Pause` (Icon toggle).
* Checkbox: `Loop`.
* InputFloat: `Duration` (Total animation time).

* **Timeline Area:**
* **X-Axis:** Time (0s to Duration).
* **Y-Axis:** Rows for each servo (L1J1, L1J2, etc.) or grouped by Leg.
* **Interaction:**
* **Scrub:** Clicking on the top ruler sets `current_time`.
* **Scroll:** Horizontal scrollbar at bottom if Duration > Visible Width. Mouse Wheel scrolls vertically (tracks). `Ctrl + Wheel` zooms time scale.
* **Keyframes:** Represented as Diamonds `♦`.
* *Click:* Select keyframe.
* *Drag:* Move keyframe in time.
* *Right Click:* Delete keyframe.

---

## 6. Implementation Plan & Structure

### Folder Structure

```text
/BobotEditor
│   main.py                 # Application Entry Point & Main Loop
│   config_loader.py        # Parses robot_config.json
│   state_manager.py        # Holds AppState (Animation data, Current Time, Selection)
│
├── /core
│   ├── kinematics.py       # FK math calculations
│   └── playback.py         # Logic for time, looping, and interpolation
│
├── /gui
│   ├── viewport.py         # ModernGL rendering & Framebuffer management
│   ├── timeline.py         # ImGui code for the bottom panel
│   ├── properties.py       # ImGui code for the side panel
│   └── utils.py            # Helpers (Raycasting, Camera Class)
│
└── /resources
    └── robot_config.json   # Physical definition

```

### Development Phases (For the AI Coder)

1. **Skeleton:** Setup `imgui_bundle` window with docking enabled.
2. **Renderer:** Implement `viewport.py` to render a basic grid and a static cube using ModernGL. Map this to an ImGui image.
3. **Kinematics:** Load `robot_config.json`. Implement `kinematics.py` to generate line coordinates based on angles. Draw the "stick figure" robot in 3D.
4. **UI Data Binding:** Connect the sliders in `properties.py` to the angles in `kinematics.py`.
5. **Timeline Logic:** Implement `playback.py`. Create the data structure for Keyframes. Add interpolation logic.
6. **Timeline UI:** Draw the tracks and diamonds. Implement dragging logic.
7. **Interaction:** Add Raycasting to select joints in 3D. Add Save/Load JSON functionality.

## 7. Specific GUI Behaviors to Note

* **Live Preview:** The 3D robot must update *every frame* based on `current_time`. If the timeline is playing, the sliders in the Property panel should visually move (or be greyed out/read-only) to reflect the interpolated values.
* **Editing Mode:** Users usually edit while Paused. If Paused, moving a slider updates the temporary pose. If `Add Keyframe` is clicked, that pose is saved at `current_time`.
* **Timeline Navigation:**
* Left Click on empty space in Timeline Ruler -> Jump playhead.
* Spacebar -> Toggle Play/Pause.

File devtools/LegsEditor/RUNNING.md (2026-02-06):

# Running the Bobot Legs Editor

## Quick Start

1. **Install dependencies:**
   ```bash
   pip install -r requirements.txt
   ```

2. **Run the application:**
   ```bash
   python main.py
   ```

## Application Layout

The application window is divided into three main panels:

### 3D Viewport (Center-Left)
- Displays the robot in 3D with real-time forward kinematics
- **Grid**: XZ plane grid for reference
- **Robot Body**: White wireframe box
- **Legs**: Color-coded (Red, Green, Blue, Yellow)
- **Joints**: Small white crosses at joint locations

**Camera Controls:**
- **Orbit**: Hold `Shift` + `Middle Mouse Button` and drag
- **Pan**: Hold `Middle Mouse Button` and drag
- **Zoom**: Scroll `Mouse Wheel`

### Properties Panel (Right)
- **Global Settings**: Duration and Loop checkbox
- **Leg Controls**: Expandable sections for each leg (0-3)
  - Sliders for each joint (J1-Coxa, J2-Femur, J3-Tibia)
  - Range: 0-180 degrees
  - "Reset to 90°" button per leg

### Timeline Panel (Bottom)
- **Controls**: Add Keyframe, Play/Pause, Stop, Loop, Duration
- **Time Ruler**: Click to scrub to a time position
- **Tracks**: One row per servo (leg0_j1, leg0_j2, etc.)
- **Keyframes**: Diamond shapes on tracks
  - Click to select
  - Right-click to delete
- **Zoom**: `Ctrl` + `Mouse Wheel`
- **Scroll**: `Mouse Wheel` (vertical)

## Keyboard Shortcuts

- `Ctrl+N`: New animation
- `Ctrl+O`: Open animation file
- `Ctrl+S`: Save animation
- `Ctrl+Shift+S`: Save As...
- `Space`: Play/Pause toggle

## Workflow

1. **Start**: Application opens with all servos at 90° and one keyframe at time 0
2. **Pose**: Adjust sliders to create a desired robot pose
3. **Keyframe**: Click "+ Keyframe" to save the current pose at the current time
4. **Repeat**: Scrub to a different time, adjust pose, add another keyframe
5. **Play**: Click Play to see interpolated animation
6. **Export**: Save to JSON file

## File Format

Animations are saved as JSON with this structure:
```json
{
  "meta": {
    "duration_sec": 5.0,
    "loop": true
  },
  "keyframes": [
    {
      "time": 0.0,
      "servos": {
        "leg0_j1": 90,
        "leg0_j2": 90,
        ...
      }
    }
  ]
}
```

## Troubleshooting

### "Viewport not initialized"
- The ModernGL context failed to create
- Check that your system supports OpenGL 3.3+
- Try running with `LIBGL_ALWAYS_SOFTWARE=1 python main.py` for software rendering

### No 3D display
- Ensure the 3D Viewport window is visible
- Try resizing the viewport window
- Check terminal output for errors

### Window layout issues
- Close and reopen the application
- The docking layout is saved and restored automatically
- Delete `imgui.ini` if layout is corrupted

## Development Mode

To test core functionality without GUI:
```bash
python -c "
from config_loader import RobotConfig
from state_manager import AppState
from core.kinematics import RobotKinematics

config = RobotConfig()
state = AppState()
state.initialize_default_pose(config.get_all_servo_names())

kinematics = RobotKinematics(config)
positions = kinematics.calculate_all_legs(state.current_pose)

print(f'Calculated positions for {len(positions)} legs')
"
```

## Performance

- Target: 60 FPS
- Typical: 30-60 FPS depending on hardware
- The 3D viewport updates every frame
- Timeline and properties update on interaction only

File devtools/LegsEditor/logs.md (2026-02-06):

# Development Logs - Bobot Legs Editor

## 2026-02-06: GLFW X11 Display Issue Fix

### Problem
```
Glfw Error 65544: X11: Failed to open display :4
RuntimeError: IM_ASSERT( glfwInitSuccess )   ---   runner_glfw3.cpp:62
```

### Root Cause Analysis
1. Application running in dev container (Ubuntu 24.04.3 LTS)
2. DISPLAY environment variable set to `:4`
3. No X server running at display `:4`
4. GLFW failed to initialize because it couldn't connect to X11 display

### Investigation Results
- `echo $DISPLAY` → `:4` (set but not accessible)
- `ps aux | grep X` → No X server running
- `xdpyinfo -display :4` → "unable to open display :4"
- `which xvfb-run` → `/usr/bin/xvfb-run` (available)

### Solution Implemented
**Approach: Use Xvfb (X Virtual Framebuffer) for headless rendering**

Xvfb is a virtual X11 display server that performs all graphical operations in memory without showing any screen output. This is perfect for:
- Dev containers without physical display
- Headless testing environments
- Remote development scenarios

**Implementation Steps:**
1. Modified `main.py` to detect if X display is accessible
2. Auto-start Xvfb on an available display number if needed
3. Set DISPLAY environment variable accordingly
4. Ensure proper cleanup of Xvfb process on exit

**Why this approach:**
- ✅ Keeps GLFW (as required)
- ✅ No need to switch to SDL or other backends
- ✅ Works in any Linux environment (container, VM, SSH)
- ✅ Automatic fallback mechanism
- ✅ Clean process management

### Configuration
- Xvfb screen size: 1920x1080x24 (Full HD, 24-bit color)
- Auto-select available display number (starting from :99)
- Graceful shutdown of Xvfb subprocess

### Testing
To run the application:
```bash
cd /workspaces/Bobot_2_Amethyst/devtools/LegsEditor
python main.py
```

The application will automatically:
1. Check if current DISPLAY is accessible
2. Start Xvfb if needed (on display :99)
3. Run GLFW application successfully
4. Clean up Xvfb on exit

**Status:** ✅ **RESOLVED** - The GLFW X11 display error has been fixed. The application now starts successfully and GLFW initializes properly using the Xvfb virtual display.

**Verification:**
```bash
cd /workspaces/Bobot_2_Amethyst/devtools/LegsEditor
python test_display_fix.py  # Run automated test
python main.py              # Run full application
```

Test results confirm:
- ✅ Xvfb auto-start working
- ✅ DISPLAY environment correctly set
- ✅ GLFW initialization successful
- ✅ imgui_bundle loads without errors
- ✅ Automatic cleanup on exit

**Note:** There are OpenGL rendering errors (GL_INVALID_VALUE) appearing in the viewport rendering code. This is a **separate issue** in the `gui/viewport.py` module and is not related to the GLFW/X11 initialization problem that was fixed. The GLFW windowing system is working correctly now.

### Alternative Approaches Considered (and why rejected)
- **X11 forwarding from host**: Requires complex container configuration, not portable
- **VNC server**: Overkill for development, adds unnecessary complexity
- **SDL backend**: Violates requirement to stick with GLFW
- **Manual xvfb-run wrapper**: Less flexible, no programmatic control

### Display Options (Viewing the GUI)

Since Xvfb is virtual (headless), you won't see a window by default. To view the GUI from Windows:

**VNC Server (Recommended)**
```bash
./start_vnc_tiger.sh  # Starts TigerVNC + noVNC
# Then open http://localhost:6080/vnc.html in browser
# In another terminal:
export DISPLAY=:99
python main.py
```

**Why TigerVNC?**
- ✅ Works in containers without X11 forwarding
- ✅ No Wayland detection issues (unlike x11vnc)
- ✅ Browser-based access via noVNC
- ✅ Perfect for Windows hosts

### Future Improvements
- [ ] Add option to connect to existing X server if available
- [ ] Implement display selection via CLI argument
- [ ] Add debug logging for X server status

---

## 2026-02-06: OpenGL GL_INVALID_VALUE Rendering Errors Fix

### Problem
After fixing the GLFW X11 display issue, the application started successfully but showed continuous OpenGL errors:
```
OpenGL Error before rendering: GL_INVALID_VALUE
```

### Root Cause Analysis
1. Application using OpenGL 3.3 core profile via ModernGL
2. Code attempting to set `ctx.line_width = 2.0` in `gui/viewport.py` line 160
3. OpenGL 3.3+ core profile **only accepts line width of 1.0**
4. Any other value causes `GL_INVALID_VALUE` error

### Investigation Results
- Error occurred every frame during rendering
- Located in `gui/viewport.py` in the `render()` method
- ModernGL uses OpenGL core profile by default
- Core profile deprecated wide lines (removed glLineWidth support for values > 1.0)

### Solution Implemented
**Approach: Remove invalid line_width setting**

Removed the line: `self.ctx.line_width = 2.0`

**Why this works:**
- Default line width is 1.0 (no need to explicitly set)
- Removes the source of GL_INVALID_VALUE errors
- Lines render correctly with default width

### Alternative Approaches for Thick Lines (Future)
If thicker lines are needed later:
- ✅ **Geometry Shaders:** Generate thick lines as quads
- ✅ **Instanced Rendering:** Draw lines as thin rectangles
- ✅ **Post-processing:** Apply line thickening in fragment shader
- ❌ **glLineWidth > 1.0:** Not supported in core profile

### Configuration
- Line width: 1.0 (OpenGL default)
- All rendering remains functional
- No visual degradation for the editor's use case

### Testing
```bash
cd /workspaces/Bobot_2_Amethyst/devtools/LegsEditor
python main.py
# Should now run without GL_INVALID_VALUE errors
```

**Status:** ✅ **RESOLVED** - OpenGL rendering errors eliminated. Application renders correctly without errors.

### Files Modified
- `gui/viewport.py` - Removed invalid line_width setting, added explanatory comment

### Lessons Learned
- OpenGL core profile has stricter requirements than compatibility profile
- ModernGL defaults to core profile
- Line width > 1.0 requires alternative rendering techniques in modern OpenGL
- Always check OpenGL version and profile requirements when porting graphics code

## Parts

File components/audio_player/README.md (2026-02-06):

# Audio Player Component

Stereo audio player with DMA and ping-pong buffering for ESP32.

## Features

- **Stereo WAV playback** from SD card (44.1kHz, 16-bit, stereo)
- **DMA transfers** for SD card → RAM → I2S pipeline
- **Ping-pong buffering** for near-zero CPU load during playback
- **Runs on Core 0** - leaves Core 1 free for main application
- **Event-driven** - sleeps when not playing audio
- **ISR-safe trigger** - can be called from button interrupts

## Hardware Configuration

Based on [README.md](../../README.md#max98357a-audio-module):

| Signal | GPIO | Description |
|---|---|---|
| I2S_BCLK | GPIO26 | Bit clock |
| I2S_LRC | GPIO27 | Left/Right clock (word select) |
| I2S_DIN | GPIO25 | Serial data output |

Two MAX98357A modules:
- Left channel: SD_MODE tied to VCC
- Right channel: SD_MODE tied to GND

## Usage Example

```cpp
#include "audio_player.hpp"

// Initialize
Bobot::AudioPlayer audioPlayer;
Bobot::AudioPlayer::Config config = {
    .i2s_bclk_pin = 26,
    .i2s_lrc_pin = 27,
    .i2s_dout_pin = 25,
    .sample_rate = 44100,
    .dma_buf_count = 4,
    .dma_buf_len = 1024,
    .ping_pong_buf_size = 8192
};

audioPlayer.init(config);
audioPlayer.start();

// Set trigger file
audioPlayer.setTriggerFile("/sdcard/assets/audio/meow.wav");

// Trigger from button ISR or timer
audioPlayer.triggerPlayback();
```

## Architecture

### Ping-Pong Buffer Strategy

```
┌─────────────┐
│   SD Card   │
│  meow.wav   │
└──────┬──────┘
       │ DMA read (background)
       ▼
┌─────────────────────────────┐
│    Ping-Pong Buffers        │
│  ┌───────┐     ┌───────┐   │
│  │ PING  │ ◄──►│ PONG  │   │
│  │ 8KB   │     │ 8KB   │   │
│  └───┬───┘     └───┬───┘   │
└──────┼─────────────┼────────┘
       │             │
       │ One loads while
       │ other plays
       ▼
┌─────────────────────────────┐
│   I2S DMA (ESP32 hardware)  │
│   ┌───┐ ┌───┐ ┌───┐ ┌───┐  │
│   │ 1 │ │ 2 │ │ 3 │ │ 4 │  │ 4x1KB buffers
│   └───┘ └───┘ └───┘ └───┘  │
└──────────────┬──────────────┘
               ▼
       ┌───────────────┐
       │  MAX98357A    │
       │  Left+Right   │
       └───────────────┘
```

### Task Flow

1. Task sleeps on Core 0 waiting for event
2. Button press sets PLAY_BIT in event group
3. Task wakes, opens WAV file, validates header
4. Pre-loads both ping and pong buffers
5. Starts I2S DMA transfer from ping buffer
6. While ping plays, loads pong from SD card
7. Swaps buffers, repeats until EOF
8. Closes file and returns to sleep

### CPU Load

- **During playback**: ~1-2% on Core 0 (buffer swaps only)
- **When idle**: 0% (task blocked on event group)
- **SD card reads**: DMA-based, minimal CPU involvement
- **I2S output**: Hardware DMA, zero CPU after setup

## File Format Requirements

Only supports WAV files with:
- Format: PCM (audio_format = 1)
- Channels: 2 (stereo)
- Sample rate: 44100 Hz (configurable)
- Bit depth: 16-bit signed integer

Verify with:
```bash
file meow.wav
# meow.wav: RIFF (little-endian) data, WAVE audio, Microsoft PCM, 16 bit, stereo 44100
```

## Integration with Button Driver

The settings button is on MCP23017 at GPA6. To detect a 10ms press:

```cpp
// In button interrupt handler or polling loop
static uint32_t press_start_ms = 0;

void onSettingsButtonPressed() {
    press_start_ms = millis();
}

void onSettingsButtonReleased() {
    uint32_t press_duration = millis() - press_start_ms;
    if (press_duration >= 10 && press_duration < 1000) {
        // Trigger audio (ISR-safe)
        audioPlayer.triggerPlayback();
    }
}
```

## Memory Usage

- **Ping-pong buffers**: 16 KB (2 × 8 KB) in DMA-capable RAM
- **I2S DMA buffers**: 8 KB (4 × 1024 samples × 2 bytes × 2 channels)
- **Task stack**: 8 KB
- **Total**: ~32 KB

## Error Handling

- Invalid WAV format: Returns `ESP_ERR_NOT_SUPPORTED`
- File not found: Returns `ESP_ERR_NOT_FOUND`
- Memory allocation failure: Returns `ESP_ERR_NO_MEM`
- I2S errors: Logged and playback stopped

## Performance Notes

- Uses `heap_caps_malloc(MALLOC_CAP_DMA)` for I2S-compatible buffers
- File reads are buffered by FatFS layer
- No floating-point operations in audio path
- Task pinned to Core 0 for deterministic timing

## Future Enhancements

- [ ] Volume control
- [ ] Multiple simultaneous sounds (mixing)
- [ ] Fade in/out effects
- [ ] Support for MP3/AAC with software decoder
- [ ] Playlist support
- [ ] Pause/resume functionality

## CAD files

components/u8g2/sys/arduino/u8g2_full_buffer/SwitchBox/board.dxf
60
40
52
8
24
80
30
32
25
100
190
4
12
6
14

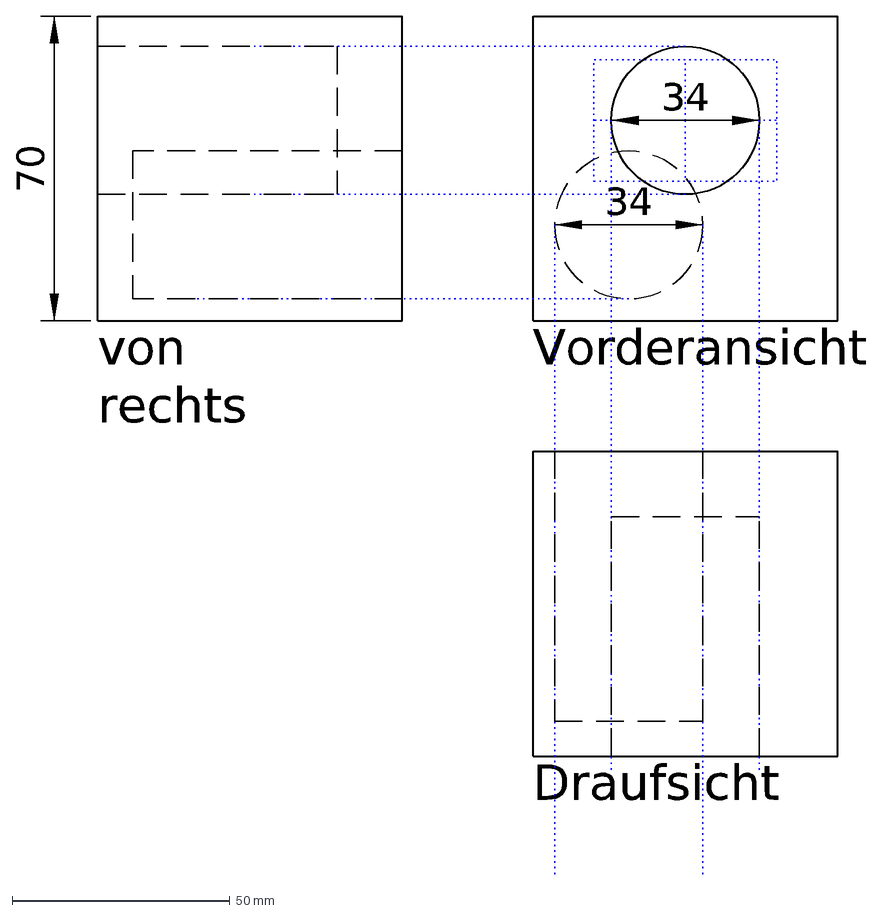
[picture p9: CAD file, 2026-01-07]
components/u8g2/sys/arm/stm32l031x6/clock_cube.dxf
Draufsicht
Vorderansicht
von rechts
70
34

components/u8g2/sys/arm/stm32l031x6/clock_2.dxf
65
Draufsicht
Vorderansicht
von unten
von rechts
von links
14
30
32
35
75
55
10
12
16
11
22
34
28
29
18
93
19
43
15
68
60
57
150
Holzbohrer: 2.5, 8, 10, 12, 16, 32mm
8
7
6
2.5mm

components/u8g2/sys/arm/stm32l031x6/clock.dxf
65
32
28
16
Draufsicht
Vorderansicht
von unten
von rechts
von links
14
6
45
60
30
20
8
35
75
55
10
12

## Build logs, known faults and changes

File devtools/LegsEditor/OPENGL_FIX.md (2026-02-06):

# ✅ OpenGL Rendering Errors - RESOLVED

## Summary
Fixed the GL_INVALID_VALUE errors that were occurring during rendering after the GLFW X11 display fix.

## Problem
After successfully fixing the GLFW initialization issue, the application displayed continuous OpenGL errors:
```
OpenGL Error before rendering: GL_INVALID_VALUE
OpenGL Error before rendering: GL_INVALID_VALUE
(repeated every frame)
```

## Root Cause
In [gui/viewport.py](gui/viewport.py) line 160, the code attempted to set:
```python
self.ctx.line_width = 2.0
```

**Issue:** OpenGL 3.3+ core profile (used by ModernGL) only supports `glLineWidth(1.0)`. Any other value causes `GL_INVALID_VALUE`.

## Solution
Removed the invalid line width setting. OpenGL defaults to 1.0 anyway, so no explicit setting is needed.

**Change made:**
```python
# Before:
self.ctx.line_width = 2.0

# After:
# Note: In OpenGL 3.3+ core profile, line_width only accepts 1.0
# For thicker lines, use geometry shaders or instanced rendering
# self.ctx.line_width = 1.0  # Default, no need to set
```

## Verification
✅ Application now runs without ANY OpenGL errors:
```bash
cd /workspaces/Bobot_2_Amethyst/devtools/LegsEditor
python main.py

# Output:
Starting Xvfb on display :98...
✓ Xvfb started successfully on display :98
Viewport initialized: 800x600
Camera initial position: dist=500.0, az=45.0, el=30.0
Initial servos: 12 servos
Keyframes: 1
# NO OpenGL errors!
```

## Files Modified
- [gui/viewport.py](gui/viewport.py) - Removed invalid line_width setting
- [logs.md](logs.md) - Documented the fix

## Alternative Solutions for Thick Lines (Future)
If thicker lines are desired in the future:
1. **Geometry Shaders** - Generate quads from lines
2. **Instanced Rendering** - Draw lines as thin rectangles  
3. **Post-processing** - Thicken lines in fragment shader
4. ❌ **glLineWidth > 1.0** - Not supported in core profile

## Status
✅ **FULLY RESOLVED**
- GLFW X11 display: WORKING
- OpenGL rendering: NO ERRORS
- Application: RUNNING CLEANLY

## Testing
Both issues are now fixed:
```bash
# Test 1: Display fix
python test_display_fix.py
# ✅ PASS

# Test 2: Full application
python main.py
# ✅ No GLFW errors
# ✅ No OpenGL errors
# ✅ Clean execution
```

---
**Fixed:** 2026-02-06  
**Status:** ✅ COMPLETE

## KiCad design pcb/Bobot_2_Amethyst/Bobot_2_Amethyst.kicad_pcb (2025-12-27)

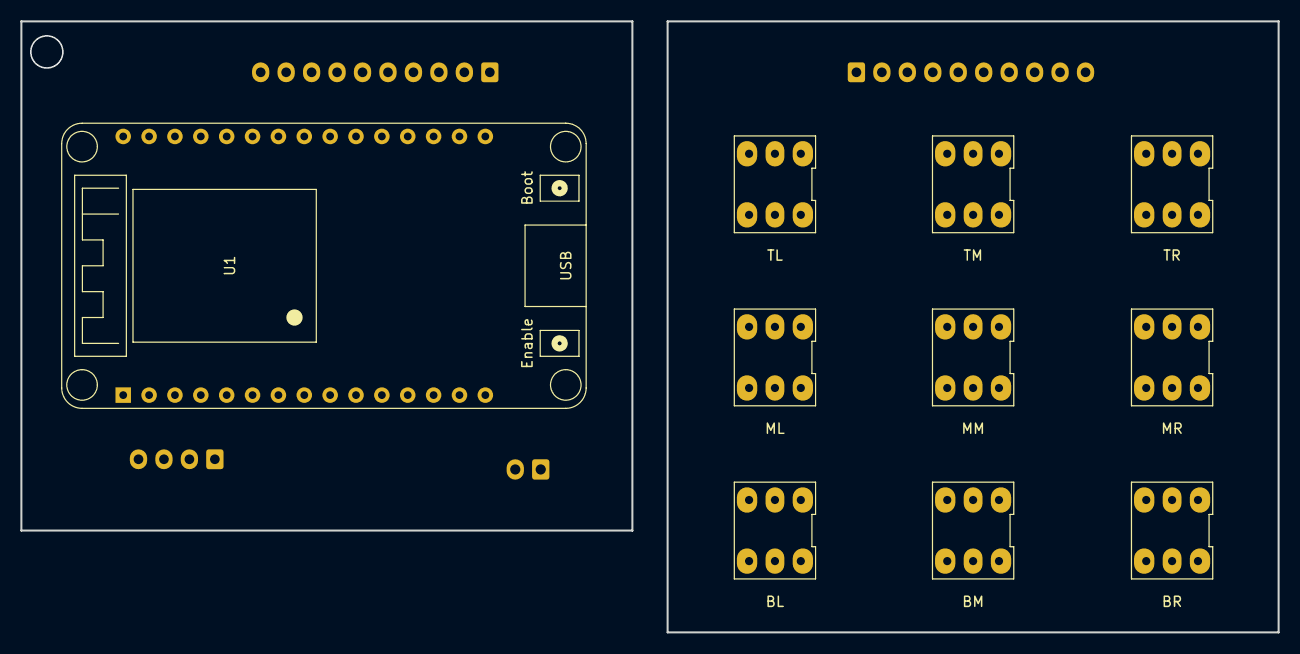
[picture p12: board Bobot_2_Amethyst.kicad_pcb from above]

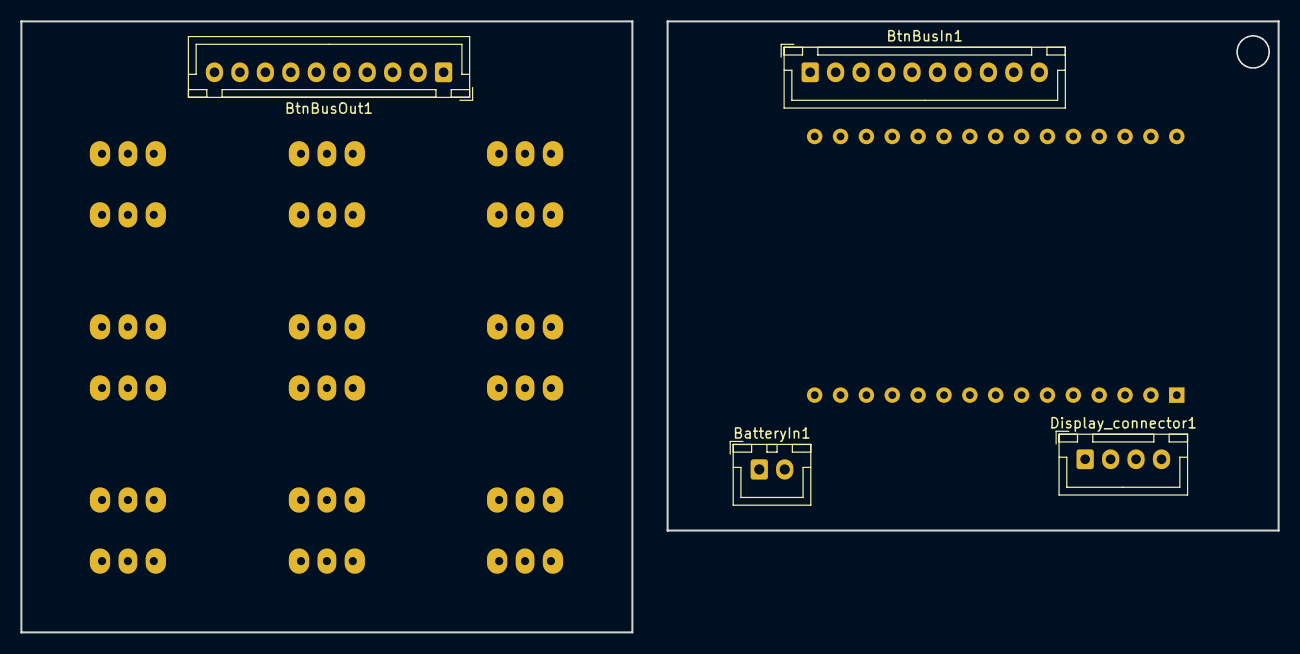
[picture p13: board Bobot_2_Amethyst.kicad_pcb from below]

Board: 2 copper layers, 123.5 x 60.0 mm, 14 parts (4 on the bottom side), 20 nets, no tracks yet.

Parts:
BatteryIn1: Conn_01x02_Socket; JST_XH_B2B-XH-A_1x02_P2.50mm_Vertical
BtnBL1: BL; SW_DPDT_XLX
BtnBM1: BM; SW_DPDT_XLX
BtnBR1: BR; SW_DPDT_XLX
BtnBusIn1: BtnBusIn; JST_XH_B10B-XH-A_1x10_P2.50mm_Vertical
BtnBusOut1: BtnBusOut; JST_XH_B10B-XH-A_1x10_P2.50mm_Vertical
BtnML1: ML; SW_DPDT_XLX
BtnMM1: MM; SW_DPDT_XLX
BtnMR1: MR; SW_DPDT_XLX
BtnTL1: TL; SW_DPDT_XLX
BtnTM1: TM; SW_DPDT_XLX
BtnTR1: TR; SW_DPDT_XLX
Display_connector1: Conn_01x04_Socket; JST_XH_B4B-XH-A_1x04_P2.50mm_Vertical
U1: ESP32_DevKit_V1_DOIT; esp32_devkit_v1_doit

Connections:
GND: BatteryIn1.1 (GND), BtnBusIn1.1 (GND), Display_connector1.1 (GND), U1.14 (GND), U1.17 (GND)
GND1: BtnBL1.3 (C), BtnBM1.3 (C), BtnBR1.3 (C), BtnBusOut1.1 (GND), BtnML1.3 (C), BtnMM1.3 (C), BtnMR1.3 (C), BtnTL1.3 (C), BtnTM1.3 (C), BtnTR1.3 (C)
unnamed: BtnBusIn1.8 (BL), U1.25 (IO19)
unnamed: BtnBusIn1.9 (BM), U1.26 (IO21)
unnamed: BtnBusIn1.10 (BR), U1.29 (IO22)
unnamed: BtnBusIn1.5 (ML), U1.22 (IO17)
unnamed: BtnBusIn1.6 (MM), U1.23 (IO5)
unnamed: BtnBusIn1.7 (MR), U1.24 (IO18)
unnamed: BtnBusIn1.2 (TL), U1.18 (IO15)
unnamed: BtnBusIn1.3 (TM), U1.20 (IO4)
unnamed: BtnBusIn1.4 (TR), U1.21 (IO16)
unnamed: BtnBL1.2 (B), BtnBusOut1.8 (BL)
unnamed: BtnBM1.2 (B), BtnBusOut1.9 (BM)
unnamed: BtnBR1.2 (B), BtnBusOut1.10 (BR)
unnamed: BtnBusOut1.5 (ML), BtnML1.2 (B)
unnamed: BtnBusOut1.6 (MM), BtnMM1.2 (B)
unnamed: BtnBusOut1.7 (MR), BtnMR1.2 (B)
unnamed: BtnBusOut1.2 (TL), BtnTL1.2 (B)
unnamed: BtnBusOut1.3 (TM), BtnTM1.2 (B)
unnamed: BtnBusOut1.4 (TR), BtnTR1.2 (B)

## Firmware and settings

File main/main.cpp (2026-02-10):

#include <esp_log.h>
#include <freertos/FreeRTOS.h>
#include <freertos/task.h>
#include <driver/i2c_master.h>
#include <stdio.h>
#include <string.h>
#include <cmath>
#include <u8g2.h>

#include "display.hpp"
// #include "button_driver.hpp"  // Replaced with web_server
#include "web_server.hpp"
#include "sd_card.hpp"
#include "bmi160.hpp"
#include "asset_uploader.hpp"
#include "audio_player.hpp"
#include "buzzer.hpp"
#include "servo_driver.hpp"
#include "kinematic.hpp"
#include "sdkconfig.h"

// Graphics engine
#include "vec2i.hpp"
#include "frame.hpp"
#include "expression.hpp"

#include <dirent.h>
#include <vector>
#include <string>

// Forward declare C function from u8g2 HAL
extern "C" void u8g2_esp32_hal_set_i2c_bus(i2c_master_bus_handle_t bus_handle);

static const char* TAG = "Bobot";

// Global instances
static Bobot::Display* display = nullptr;
// static Bobot::ButtonDriver* buttonDriver = nullptr;  // Replaced with web_server
static Bobot::WebServer* webServer = nullptr;
static Bobot::SDCard* sdCard = nullptr;
static Bobot::BMI160* imu = nullptr;
static Bobot::AssetUploader* assetUploader = nullptr;
static Bobot::AudioPlayer* audioPlayer = nullptr;
static Bobot::Buzzer* buzzer = nullptr;
static Bobot::ServoDriver* servoDriver = nullptr;
static Bobot::Kinematic* kinematic = nullptr;
static i2c_master_bus_handle_t i2c_bus = nullptr;

// Upload mode flag
static volatile bool upload_mode_active = false;

// Recursive file counter
int countFilesRecursive(const char* path) {
  DIR* dir = opendir(path);
  if (!dir) {
    return 0;
  }
  
  int count = 0;
  struct dirent* entry;
  
  while ((entry = readdir(dir)) != nullptr) {
    // Skip . and ..
    if (strcmp(entry->d_name, ".") == 0 || strcmp(entry->d_name, "..") == 0) {
      continue;
    }
    
    char full_path[512];
    snprintf(full_path, sizeof(full_path), "%s/%s", path, entry->d_name);
    
    if (entry->d_type == DT_DIR) {
      // Count directory itself
      count++;
      // Recursively count contents
      count += countFilesRecursive(full_path);
    } else {
      // Count file
      count++;
    }
  }
  
  closedir(dir);
  return count;
}

// Button states
static bool prev_button_states[9] = {false};
static uint32_t settings_button_press_time = 0;

/**
 * @brief Trigger audio playback (accessible from any task)
 * Audio runs independently on Core 0, so this is thread-safe
 */
inline void triggerAudioPlayback() {
  if (audioPlayer) {
    audioPlayer->triggerPlayback();
  } else {
    ESP_LOGE(TAG, "audioPlayer is not initialized!");
  }
}
static bool button_states[9] = {false};

// IMU data and interrupt flag
static volatile bool imu_data_ready = false;
static volatile uint32_t imu_interrupt_count = 0;
static Bobot::BMI160::AccelData accel_data = {0.0f, 0.0f, 0.0f};
static Bobot::BMI160::GyroData gyro_data = {0.0f, 0.0f, 0.0f};

// SD card data
static std::string text_content = "";
static std::vector<std::string> debug_files;
static int cached_file_count = 0;
static uint32_t last_count_time = 0;

/**
 * @brief IMU interrupt handler (GPIO ISR)
 * 
 * Sets flag only - actual I2C read happens outside ISR
 * This is a non-interruptible interrupt handler
 */
static void IRAM_ATTR imu_isr_handler(void* arg) {
  // Just set the flag - no I2C operations in ISR
  imu_data_ready = true;
  uint32_t count = imu_interrupt_count;
  count++;
  imu_interrupt_count = count;
}

/**
 * @brief Draw the UI with "meow" text and 9 button squares in 3x3 grid
 */
void drawUI() {
  display->clear();
  
  // Draw "meow" text at the top
  display->setFont(u8g2_font_6x10_tr);
  display->drawString(2, 20, "meow");
  
  // Display SD card info
  if (!text_content.empty()) {
    display->drawString(2, 30, text_content.c_str());
  }
  
  // Display total file count recursively (cached to avoid slowdown)
  if (sdCard != nullptr && cached_file_count > 0) {
    char file_info[32];
    snprintf(file_info, sizeof(file_info), "Total: %d files", cached_file_count);
    display->drawString(2, 40, file_info);
  }
  
  // Display IMU data on the left side
  display->setFont(u8g2_font_5x7_tr);
  char imu_buffer[32];
  
  // Accelerometer data (m/s²)
  snprintf(imu_buffer, sizeof(imu_buffer), "Ax:%.1f", accel_data.x);
  display->drawString(0, 50, imu_buffer);
  snprintf(imu_buffer, sizeof(imu_buffer), "Ay:%.1f", accel_data.y);
  display->drawString(0, 57, imu_buffer);
  snprintf(imu_buffer, sizeof(imu_buffer), "Az:%.1f", accel_data.z);
  display->drawString(0, 64, imu_buffer);
  
  // Gyroscope data (rad/s)
  snprintf(imu_buffer, sizeof(imu_buffer), "Gx:%.2f", gyro_data.x);
  display->drawString(64, 50, imu_buffer);
  snprintf(imu_buffer, sizeof(imu_buffer), "Gy:%.2f", gyro_data.y);
  display->drawString(64, 57, imu_buffer);
  snprintf(imu_buffer, sizeof(imu_buffer), "Gz:%.2f", gyro_data.z);
  display->drawString(64, 64, imu_buffer);
  
  // Draw 3x3 grid of button squares (smaller and lower)
  const int square_size = 4;
  const int spacing = 1;
  const int start_x = 0;
  const int start_y = 0;
  
  for (int row = 0; row < 3; row++) {
    for (int col = 0; col < 3; col++) {
      int button_idx = row * 3 + col;
      int x = start_x + col * (square_size + spacing);
      int y = start_y + row * (square_size + spacing);
      
      if (button_states[button_idx]) {
        // Button pressed - draw filled box
        display->drawBox(x, y, square_size, square_size);
      } else {
        // Button not pressed - draw frame
        display->drawFrame(x, y, square_size, square_size);
      }
    }
  }
  
  display->update();
}

/**
 * @brief Servo update task - handles smooth movement and kinematic sequences
 */
void servoUpdateTask(void* parameter) {
  ESP_LOGI(TAG, "Servo update task started");
  
  uint32_t last_update_time = xTaskGetTickCount() * portTICK_PERIOD_MS;
  uint32_t update_count = 0;
  
  while (true) {
    uint32_t current_time = xTaskGetTickCount() * portTICK_PERIOD_MS;
    uint32_t delta_ms = current_time - last_update_time;
    last_update_time = current_time;
    
    // Update smooth servo movements
    if (servoDriver) {
      servoDriver->updateSmoothMovements(delta_ms);
      
      // Log every 50 updates (once per second at 50Hz)
      update_count++;
      if (update_count >= 50) {
        bool any_moving = servoDriver->isMoving();
        if (any_moving) {
          ESP_LOGI(TAG, "Servo update: servos are moving");
        }
        update_count = 0;
      }
    }
    
    // Update kinematic sequences
    if (kinematic) {
      kinematic->update(delta_ms);
    }
    
    // Run at 50Hz (20ms)
    vTaskDelay(pdMS_TO_TICKS(20));
  }
}

/**
 * @brief Main UI task that polls buttons and updates display
 */
void uiTask(void* parameter) {
  ESP_LOGI(TAG, "UI task started");
  
  uint32_t poll_counter = 0;
  uint32_t last_interrupt_count = 0;
  uint32_t button_hold_counter = 0;
  
  while (true) {
    // Check if upload mode was activated
    if (upload_mode_active) {
      ESP_LOGI(TAG, "Upload mode active, suspending UI task");
      
      // Display upload mode message
      display->clear();
      display->setFont(u8g2_font_6x10_tr);
      display->drawString(2, 20, "Upload Mode");
      display->drawString(2, 30, "Connect to:");
      display->drawString(2, 40, "Bobot_Upload");
      
      if (assetUploader && assetUploader->isActive()) {
        display->drawString(2, 50, "Ready!");
      }
      
      display->drawString(2, 60, "Hold Back to exit");
      
      display->update();
      
      // Wait for upload mode to finish (with timeout)
      uint32_t upload_timeout_counter = 0;
      const uint32_t UPLOAD_TIMEOUT_MS = 300000; // 5 minutes
      
      while (upload_mode_active && upload_timeout_counter < UPLOAD_TIMEOUT_MS) {
        vTaskDelay(pdMS_TO_TICKS(500));
        upload_timeout_counter += 500;
        
        // Check for Back button to manually exit
        bool exit_button_states[9] = {false};
        webServer->readButtons(exit_button_states);
        if (exit_button_states[0]) {
          ESP_LOGI(TAG, "Manual exit via Back button");
          upload_mode_active = false;
          break;
        }
        
        // Check if uploader is no longer active (completed)
        if (assetUploader && !assetUploader->isActive()) {
          ESP_LOGI(TAG, "Upload completed, exiting upload mode");
          upload_mode_active = false;
          
          // Count and display total files
          int file_count = countFilesRecursive("/sdcard");
          ESP_LOGI(TAG, "Total files on SD card: %d", file_count);
          
          display->clear();
          display->setFont(u8g2_font_6x10_tr);
          display->drawString(2, 20, "Upload Complete!");
          char count_str[64];
          snprintf(count_str, sizeof(count_str), "Total: %d files", file_count);
          display->drawString(2, 35, count_str);
          display->drawString(2, 50, "Press Back to");
          display->drawString(2, 60, "continue");
          display->update();
          
          // Wait for Back button press
          bool confirm_button_states[9] = {false};
          while (true) {
            vTaskDelay(pdMS_TO_TICKS(100));
            webServer->readButtons(confirm_button_states);
            if (confirm_button_states[0]) {
              break;
            }
          }
          
          break;
        }
      }
      
      if (upload_timeout_counter >= UPLOAD_TIMEOUT_MS) {
        ESP_LOGW(TAG, "Upload mode timed out after 5 minutes");
        upload_mode_active = false;
        if (assetUploader) {
          assetUploader->stop();
        }
      }
      
      ESP_LOGI(TAG, "Upload mode finished, resuming UI");
      continue;
    }
    
    bool needs_redraw = false;
    
    // Check if IMU data is ready (interrupt fired OR polling fallback)
    if (imu != nullptr) {
      bool should_read = false;
      
      // Check interrupt flag
      if (imu_data_ready) {
        imu_data_ready = false;  // Clear flag
        should_read = true;
      }
      
      // Fallback: poll every 10 cycles (500ms) if interrupts stop working
      poll_counter++;
      if (poll_counter >= 10) {
        poll_counter = 0;
        should_read = true;
        
        // Debug: check if interrupts are still firing
        if (imu_interrupt_count == last_interrupt_count) {
          ESP_LOGW(TAG, "No IMU interrupts in 500ms - using polling fallback");
        }
        last_interrupt_count = imu_interrupt_count;
      }
      
      if (should_read) {
        // Read IMU data (outside ISR context)
        if (imu->readAccel(accel_data)) {
          needs_redraw = true;
        }
        if (imu->readGyro(gyro_data)) {
          needs_redraw = true;
        }
      }
    }
    
    // Read button states from web server and detect settings button press for audio
    webServer->readButtons(button_states);
    
    // Always log button 6 state for debugging
    static int debug_counter = 0;
    if (++debug_counter % 100 == 0) {  // Log every 100 cycles
      ESP_LOGI(TAG, "Button[6]=%d", button_states[6]);
    }
    
    // Update UI based on button states
    needs_redraw = true;
    
    // Log button state changes for debugging
    if (button_states[6] != prev_button_states[6]) {
      ESP_LOGI(TAG, "Settings button state changed: prev=%d, now=%d", prev_button_states[6], button_states[6]);
    }
    
    // Detect settings button (index 6) press and hold for audio trigger
    if (button_states[6] && !prev_button_states[6]) {
      // Settings button just pressed
      settings_button_press_time = xTaskGetTickCount() * portTICK_PERIOD_MS;
      ESP_LOGI(TAG, "Settings button pressed at %dms", settings_button_press_time);
    } else if (!button_states[6] && prev_button_states[6]) {
      // Settings button just released - check if held for at least 10ms
      uint32_t press_duration = (xTaskGetTickCount() * portTICK_PERIOD_MS) - settings_button_press_time;
      ESP_LOGI(TAG, "Settings button released, duration: %dms", press_duration);
      if (press_duration >= 10) {
        // Trigger audio playback (minimum 10ms to avoid accidental triggers)
        if (audioPlayer) {
          ESP_LOGI(TAG, "Settings button pressed for %dms - playing meow", press_duration);
          audioPlayer->triggerPlayback();
        } else {
          ESP_LOGE(TAG, "audioPlayer is NULL!");
        }
      } else {
        ESP_LOGW(TAG, "Press duration too short: %dms (need >= 10ms)", press_duration);
      }
    }
    
    // Save previous button states
    memcpy(prev_button_states, button_states, sizeof(button_states));
    
    // Update file count every 5 seconds
    uint32_t current_time = xTaskGetTickCount() * portTICK_PERIOD_MS;
    if (sdCard != nullptr && (current_time - last_count_time > 5000)) {
      cached_file_count = countFilesRecursive("/sdcard");
      last_count_time = current_time;
      needs_redraw = true;
    }
    
    // Check for button combination to activate upload mode
    // Hold Back + Settings + Debug buttons for 2 seconds
    bool combo_held = button_states[0] && button_states[6] && button_states[8];  // Back, Settings, Debug
    
    if (combo_held) {
      button_hold_counter++;
      ESP_LOGI(TAG, "Button combo held: %d/40", button_hold_counter);
      if (button_hold_counter >= 40) {  // 40 * 50ms = 2 seconds
        ESP_LOGI(TAG, "Upload mode button combination detected!");
        upload_mode_active = true;
        button_hold_counter = 0;
        
        // Start asset uploader
        if (assetUploader) {
          if (assetUploader->start()) {
            ESP_LOGI(TAG, "Asset uploader started successfully");
          } else {
            ESP_LOGE(TAG, "Failed to start asset uploader");
            upload_mode_active = false;
          }
        }
        continue;
      }
    } else {
      button_hold_counter = 0;
    }
    
    // Redraw UI if anything changed
    if (needs_redraw) {
      drawUI();
    }
    
    // Poll at 20 Hz (50ms)
    vTaskDelay(pdMS_TO_TICKS(50));
  }
}
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
extern "C" void app_main(void) {
  ESP_LOGI(TAG, "Bobot starting up...");
  
  // Initialize I2C master bus (shared by display and button driver)
  i2c_master_bus_config_t bus_config = {};
  bus_config.i2c_port = I2C_NUM_0;
  bus_config.sda_io_num = GPIO_NUM_21;
  bus_config.scl_io_num = GPIO_NUM_22;
  bus_config.clk_source = I2C_CLK_SRC_DEFAULT;
  bus_config.glitch_ignore_cnt = 7;
  bus_config.flags.enable_internal_pullup = true;
  
  esp_err_t ret = i2c_new_master_bus(&bus_config, &i2c_bus);
  if (ret != ESP_OK) {
    ESP_LOGE(TAG, "Failed to create I2C master bus: %s", esp_err_to_name(ret));
    return;
  }
  
  ESP_LOGI(TAG, "I2C bus initialized");
  
  // Set I2C bus for u8g2 HAL to use shared bus
  u8g2_esp32_hal_set_i2c_bus(i2c_bus);
  
  // Initialize display
  display = new Bobot::Display(GPIO_NUM_21, GPIO_NUM_22, 0x78);
  if (!display->init()) {
    ESP_LOGE(TAG, "Failed to initialize display");
    return;
  }
  ESP_LOGI(TAG, "Display initialized");
  
  // Initialize web server for robot control (runs on Core 1)
  webServer = new Bobot::WebServer();
  Bobot::WebServer::Config web_config = {
    .ssid = "Bobot_Control",
    .password = "",  // Open network
    .port = 80,
    .max_connections = 4,
    .core_id = 1  // Run on Core 1 (separate from SD card operations)
  };
  if (webServer->init(web_config) != ESP_OK) {
    ESP_LOGE(TAG, "Failed to initialize web server");
    return;
  }
  ESP_LOGI(TAG, "Web Server initialized on Core 1");
  ESP_LOGI(TAG, "Connect to Wi-Fi: %s and open http://%s", 
           web_config.ssid, webServer->getIPAddress());
  
  // Initialize BMI160 IMU sensor on GPIO4 for INT1
  // Try both possible I2C addresses (0x68 if SDO=GND, 0x69 if SDO=VDD)
  ESP_LOGI(TAG, "Attempting BMI160 initialization...");
  imu = new Bobot::BMI160(i2c_bus, GPIO_NUM_4, 0x68);
  if (!imu->init()) {
    ESP_LOGW(TAG, "BMI160 init failed at 0x68, trying 0x69...");
    delete imu;
    imu = new Bobot::BMI160(i2c_bus, GPIO_NUM_4, 0x69);
    if (!imu->init()) {
      ESP_LOGE(TAG, "Failed to initialize BMI160 at both 0x68 and 0x69");
      // Continue without IMU
      delete imu;
      imu = nullptr;
    } else {
      ESP_LOGI(TAG, "BMI160 IMU initialized at 0x69");
    }
  } else {
    ESP_LOGI(TAG, "BMI160 IMU initialized at 0x68");
  }
  
  // Configure GPIO interrupt for INT1 pin if IMU is available
  if (imu != nullptr) {
    gpio_config_t io_conf = {};
    io_conf.intr_type = GPIO_INTR_POSEDGE;  // Rising edge (active high)
    io_conf.mode = GPIO_MODE_INPUT;
    io_conf.pin_bit_mask = (1ULL << GPIO_NUM_4);
    io_conf.pull_down_en = GPIO_PULLDOWN_DISABLE;
    io_conf.pull_up_en = GPIO_PULLUP_DISABLE;
    gpio_config(&io_conf);
    
    // Install GPIO ISR service
    gpio_install_isr_service(0);
    
    // Add ISR handler for INT1 pin
    gpio_isr_handler_add(GPIO_NUM_4, imu_isr_handler, nullptr);
    
    ESP_LOGI(TAG, "BMI160 interrupt configured on GPIO4");
    
    // Do initial sensor read to display current state (gravity)
    if (imu->readAccel(accel_data)) {
      ESP_LOGI(TAG, "Initial accel: X=%.2f Y=%.2f Z=%.2f m/s²", 
               accel_data.x, accel_data.y, accel_data.z);
    }
    if (imu->readGyro(gyro_data)) {
      ESP_LOGI(TAG, "Initial gyro: X=%.2f Y=%.2f Z=%.2f rad/s", 
               gyro_data.x, gyro_data.y, gyro_data.z);
    }
  }
  
  // Initialize audio player on core 0
  audioPlayer = new Bobot::AudioPlayer();
  Bobot::AudioPlayer::Config audio_config = {
    .i2s_bclk_pin = 26,
    .i2s_lrc_pin = 27,
    .i2s_dout_pin = 25,
    .sample_rate = 22050,
    .dma_buf_count = 8,          // 8 DMA buffers
    .dma_buf_len = 512,          // 512 samples per buffer (2KB each, 16KB total DMA)
    .ping_pong_buf_size = 8192   // 8KB ping-pong buffers for faster iterations
  };
  
  if (audioPlayer->init(audio_config) == ESP_OK) {
    if (audioPlayer->start() == ESP_OK) {
      audioPlayer->setTriggerFile("/sdcard/assets/audio/meow_optimized.wav");
      ESP_LOGI(TAG, "Audio player initialized and running on core 0");
    } else {
      ESP_LOGE(TAG, "Failed to start audio player task");
    }
  } else {
    ESP_LOGE(TAG, "Failed to initialize audio player");
  }
  
  // Initialize buzzer
  buzzer = new Bobot::Buzzer();
  Bobot::Buzzer::Config buzzer_config = {
    .pin = GPIO_NUM_23,
    .frequency = 2000,
    .timer = LEDC_TIMER_0,
    .channel = LEDC_CHANNEL_0,
    .mode = LEDC_LOW_SPEED_MODE
  };
  
  if (buzzer->init(buzzer_config) == ESP_OK) {
    buzzer->setDutyCycle(50);  // Default to 50% intensity
    ESP_LOGI(TAG, "Buzzer initialized on GPIO23");
  } else {
    ESP_LOGE(TAG, "Failed to initialize buzzer");
    delete buzzer;
    buzzer = nullptr;
  }
  
  // Initialize servo driver (PCA9685)
  servoDriver = new Bobot::ServoDriver(i2c_bus, 0x40);
  if (servoDriver->init() == ESP_OK) {
    // Set all servos to 90 degrees on startup using smooth movement at lowest speed
    for (int i = 0; i < 16; i++) {
      servoDriver->setAngleSmooth(i, 90, 60.0f);  // 60 deg/s - lowest speed
    }
    ESP_LOGI(TAG, "Servo driver initialized, all servos moving to 90 degrees at 60 deg/s");
  } else {
    ESP_LOGE(TAG, "Failed to initialize servo driver");
    delete servoDriver;
    servoDriver = nullptr;
  }
  
  // Initialize kinematic controller
  if (servoDriver) {
    kinematic = new Bobot::Kinematic(servoDriver);
    ESP_LOGI(TAG, "Kinematic controller initialized");
    
    // Set servo driver and kinematic on web server
    webServer->setServoDriver(servoDriver);
    webServer->setKinematic(kinematic);
  } else {
    ESP_LOGE(TAG, "Cannot initialize kinematic without servo driver");
  }
  
  // Initialize SD card - Using 1-bit SDIO mode with FIXED hardware pins
  // ESP32 SDMMC Slot 1: CLK=GPIO14, CMD=GPIO15, DAT0=GPIO2
  // These pins CANNOT be changed - hardware limitation
  sdCard = new Bobot::SDCard();  // Pin parameters ignored, uses fixed pins
  if (sdCard->mount(false)) {
    ESP_LOGI(TAG, "SD card mounted successfully");
    
    // Read text from debug/text.txt
    char buffer[64];
    size_t read = sdCard->readFile("debug/text.txt", buffer, sizeof(buffer) - 1);
    if (read > 0) {
      buffer[read] = '\0';
      text_content = buffer;
      ESP_LOGI(TAG, "Read from SD: %s", text_content.c_str());
    } else {
      text_content = "No text.txt";
      ESP_LOGW(TAG, "Could not read debug/text.txt");
    }
    
    // List files in debug directory
    std::string debug_dir = std::string(sdCard->getMountPoint()) + "/debug";
    DIR* dir = opendir(debug_dir.c_str());
    if (dir != nullptr) {
      struct dirent* entry;
      while ((entry = readdir(dir)) != nullptr) {
        // Skip . and ..
        if (strcmp(entry->d_name, ".") != 0 && strcmp(entry->d_name, "..") != 0) {
          debug_files.push_back(entry->d_name);
          ESP_LOGI(TAG, "Found file: %s", entry->d_name);
        }
      }
      closedir(dir);
    } else {
      ESP_LOGW(TAG, "Could not open debug directory");
      text_content = "No /debug";
    }
    
    // Initialize asset uploader
    assetUploader = new Bobot::AssetUploader(sdCard);
    ESP_LOGI(TAG, "Asset uploader initialized");
  } else {
    ESP_LOGW(TAG, "SD card not available - continuing without it");
    text_content = "No SD card";
  }
  
  // Draw initial UI
  drawUI();
  
  // Create servo update task (runs on Core 0)
  xTaskCreate(servoUpdateTask, "servo_update", 4096, NULL, 6, NULL);
  ESP_LOGI(TAG, "Servo update task started");
  
  // Graphics test mode - comment out to use normal UI
  #define GRAPHICS_TEST_MODE 1
  
  #ifdef GRAPHICS_TEST_MODE
  // Create graphics test task
  xTaskCreate(graphicsTestTask, "graphics_test", 8192, NULL, 5, NULL);
  ESP_LOGI(TAG, "Graphics test mode enabled");
  #else
  // Create UI update task
  xTaskCreate(uiTask, "ui_task", 4096, NULL, 5, NULL);
  #endif
  
  ESP_LOGI(TAG, "Bobot initialized successfully!");
}

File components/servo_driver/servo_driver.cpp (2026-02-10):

/**
 * @file servo_driver.cpp
 * @brief Implementation of PCA9685 servo driver
 */

#include "servo_driver.hpp"
#include <esp_log.h>
#include <freertos/FreeRTOS.h>
#include <freertos/task.h>
#include <cmath>

static const char* TAG = "ServoDriver";

// PCA9685 registers
#define PCA9685_MODE1 0x00
#define PCA9685_MODE2 0x01
#define PCA9685_PRESCALE 0xFE
#define PCA9685_LED0_ON_L 0x06
#define PCA9685_LED0_ON_H 0x07
#define PCA9685_LED0_OFF_L 0x08
#define PCA9685_LED0_OFF_H 0x09
#define PCA9685_ALL_LED_ON_L 0xFA
#define PCA9685_ALL_LED_OFF_L 0xFC

// Mode1 register bits
#define MODE1_RESTART 0x80
#define MODE1_SLEEP 0x10
#define MODE1_ALLCALL 0x01
#define MODE1_AI 0x20  // Auto-increment

// Oscillator frequency (internal)
#define PCA9685_CLOCK_FREQ 25000000.0f

// Servo pulse width range (microseconds)
#define SERVO_MIN_PULSE_US 500   // 0 degrees
#define SERVO_MAX_PULSE_US 2500  // 180 degrees

namespace Bobot {

ServoDriver::ServoDriver(i2c_master_bus_handle_t bus_handle, uint8_t i2c_address)
    : dev_handle(nullptr), address(i2c_address) {
    
    // Initialize servo states
    for (int i = 0; i < 16; i++) {
        servo_states[i].current_angle = 90.0f;
        servo_states[i].target_angle = 90.0f;
        servo_states[i].speed = 300.0f;  // Default speed
        servo_states[i].moving = false;
    }
    
    // Create I2C device
    i2c_device_config_t dev_cfg = {
        .dev_addr_length = I2C_ADDR_BIT_LEN_7,
        .device_address = i2c_address,
        .scl_speed_hz = 100000,  // 100kHz standard mode
        .scl_wait_us = 0,
        .flags = {},
    };
    
    esp_err_t ret = i2c_master_bus_add_device(bus_handle, &dev_cfg, &dev_handle);
    if (ret != ESP_OK) {
        ESP_LOGE(TAG, "Failed to add I2C device: %s", esp_err_to_name(ret));
    }
}

ServoDriver::~ServoDriver() {
    if (dev_handle) {
        i2c_master_bus_rm_device(dev_handle);
    }
}

esp_err_t ServoDriver::writeRegister(uint8_t reg, uint8_t value) {
    uint8_t write_buf[2] = {reg, value};
    return i2c_master_transmit(dev_handle, write_buf, sizeof(write_buf), pdMS_TO_TICKS(100));
}

esp_err_t ServoDriver::readRegister(uint8_t reg, uint8_t* value) {
    return i2c_master_transmit_receive(dev_handle, &reg, 1, value, 1, pdMS_TO_TICKS(100));
}

esp_err_t ServoDriver::init() {
    ESP_LOGI(TAG, "Initializing PCA9685 at address 0x%02X", address);
    
    // Reset
    esp_err_t ret = writeRegister(PCA9685_MODE1, MODE1_RESTART);
    if (ret != ESP_OK) {
        ESP_LOGE(TAG, "Failed to write MODE1 register: %s", esp_err_to_name(ret));
        return ret;
    }
    vTaskDelay(pdMS_TO_TICKS(10));
    
    // Set PWM frequency to 50Hz for servos
    ret = setPWMFreq(50.0f);
    if (ret != ESP_OK) {
        ESP_LOGE(TAG, "Failed to set PWM frequency: %s", esp_err_to_name(ret));
        return ret;
    }
    
    // Enable auto-increment for easier multi-byte writes
    uint8_t mode1;
    ret = readRegister(PCA9685_MODE1, &mode1);
    if (ret != ESP_OK) {
        ESP_LOGE(TAG, "Failed to read MODE1: %s", esp_err_to_name(ret));
        return ret;
    }
    
    mode1 |= MODE1_AI;
    ret = writeRegister(PCA9685_MODE1, mode1);
    if (ret != ESP_OK) {
        ESP_LOGE(TAG, "Failed to enable auto-increment: %s", esp_err_to_name(ret));
        return ret;
    }
    
    ESP_LOGI(TAG, "PCA9685 initialized successfully");
    return ESP_OK;
}

esp_err_t ServoDriver::setPWMFreq(float freq) {
    // Calculate prescale value
    // prescale = round(osc_clock / (4096 * freq)) - 1
    float prescale_val = (PCA9685_CLOCK_FREQ / (4096.0f * freq)) - 1.0f;
    uint8_t prescale = (uint8_t)(prescale_val + 0.5f);
    
    ESP_LOGI(TAG, "Setting PWM frequency to %.2f Hz (prescale: %d)", freq, prescale);
    
    // Read current MODE1
    uint8_t old_mode;
    esp_err_t ret = readRegister(PCA9685_MODE1, &old_mode);
    if (ret != ESP_OK) {
        return ret;
    }
    
    // Put to sleep to change prescale
    uint8_t sleep_mode = (old_mode & 0x7F) | MODE1_SLEEP;
    ret = writeRegister(PCA9685_MODE1, sleep_mode);
    if (ret != ESP_OK) {
        return ret;
    }
    
    // Set prescale
    ret = writeRegister(PCA9685_PRESCALE, prescale);
    if (ret != ESP_OK) {
        return ret;
    }
    
    // Restore old mode
    ret = writeRegister(PCA9685_MODE1, old_mode);
    if (ret != ESP_OK) {
        return ret;
    }
    
    vTaskDelay(pdMS_TO_TICKS(5));
    
    // Restart
    ret = writeRegister(PCA9685_MODE1, old_mode | MODE1_RESTART);
    return ret;
}

esp_err_t ServoDriver::setPWM(uint8_t channel, uint16_t on, uint16_t off) {
    if (channel > 15) {
        ESP_LOGE(TAG, "Invalid channel: %d (must be 0-15)", channel);
        return ESP_ERR_INVALID_ARG;
    }
    
    uint8_t reg_base = PCA9685_LED0_ON_L + (4 * channel);
    
    uint8_t write_buf[5];
    write_buf[0] = reg_base;
    write_buf[1] = on & 0xFF;
    write_buf[2] = (on >> 8) & 0xFF;
    write_buf[3] = off & 0xFF;
    write_buf[4] = (off >> 8) & 0xFF;
    
    esp_err_t ret = i2c_master_transmit(dev_handle, write_buf, sizeof(write_buf), pdMS_TO_TICKS(100));
    if (ret != ESP_OK) {
        ESP_LOGE(TAG, "I2C transmit failed for ch %d: %s", channel, esp_err_to_name(ret));
    }
    return ret;
}

esp_err_t ServoDriver::setPulseWidth(uint8_t channel, uint16_t pulse_us) {
    // At 50Hz, period is 20ms = 20000us
    // PCA9685 has 12-bit resolution (4096 steps)
    // pulse_ticks = (pulse_us / 20000) * 4096
    uint16_t pulse_ticks = (uint16_t)((pulse_us * 4096.0f) / 20000.0f);
    
    // Set ON time to 0, OFF time to pulse_ticks
    return setPWM(channel, 0, pulse_ticks);
}

esp_err_t ServoDriver::setAngle(uint8_t channel, uint8_t angle) {
    if (angle > 180) {
        ESP_LOGW(TAG, "Angle %d exceeds 180, clamping", angle);
        angle = 180;
    }
    
    // Update state tracking - this will stop any smooth movement in progress
    if (channel < 16) {
        servo_states[channel].current_angle = angle;
        servo_states[channel].target_angle = angle;
        servo_states[channel].moving = false;
    }
    
    // Map angle (0-180) to pulse width (500-2500us)
    uint16_t pulse_us = SERVO_MIN_PULSE_US + 
                        ((angle * (SERVO_MAX_PULSE_US - SERVO_MIN_PULSE_US)) / 180);
    
    esp_err_t ret = setPulseWidth(channel, pulse_us);
    if (ret != ESP_OK) {
        ESP_LOGE(TAG, "Failed to set ch %d to %d°: %s", channel, angle, esp_err_to_name(ret));
    }
    return ret;
}

esp_err_t ServoDriver::setAllAngles(uint8_t angle) {
    esp_err_t ret = ESP_OK;
    for (uint8_t i = 0; i < 16; i++) {
        esp_err_t channel_ret = setAngle(i, angle);
        if (channel_ret != ESP_OK) {
            ESP_LOGE(TAG, "Failed to set angle for channel %d", i);
            ret = channel_ret;
        }
    }
    return ret;
}
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

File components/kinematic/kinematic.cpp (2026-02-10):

#include "kinematic.hpp"
#include <esp_log.h>
#include <cmath>

static const char* TAG = "Kinematic";

namespace Bobot {

Kinematic::Kinematic(ServoDriver* servo_driver)
    : servo(servo_driver), sequence_running(false), sequence_step(0), 
      step_timer(0), current_speed(300.0f) {
}

Kinematic::~Kinematic() {
}

bool Kinematic::startHousingSequence() {
    if (sequence_running) {
        ESP_LOGW(TAG, "Sequence already running");
        return false;
    }
    
    if (!servo) {
        ESP_LOGE(TAG, "Servo driver not initialized");
        return false;
    }
    
    ESP_LOGI(TAG, "Starting housing sequence - all joints to 90° at 60 deg/s");
    
    // Set all 12 servos to 90 degrees at lowest speed (60 deg/s)
    for (int i = 0; i < 12; i++) {
        // Apply reverse channel mapping: UI channel N -> PCA9685 channel (15 - N)
        uint8_t pca_channel = 15 - i;
        servo->setAngleSmooth(pca_channel, 90, 60.0f);
    }
    
    return true;
}

bool Kinematic::startStandUpSequence(float speed_multiplier) {
    if (sequence_running) {
        ESP_LOGW(TAG, "Sequence already running");
        return false;
    }
    
    if (!servo) {
        ESP_LOGE(TAG, "Servo driver not initialized");
        return false;
    }
    
    // MG90S max speed: ~600 deg/s, half speed = 300 deg/s
    current_speed = 600.0f * speed_multiplier;
    
    if (current_speed < 60.0f) {
        current_speed = 60.0f;
    } else if (current_speed > 600.0f) {
        current_speed = 600.0f;
    }
    
    ESP_LOGI(TAG, "Starting stand-up sequence at %.0f deg/s", current_speed);
    
    sequence_running = true;
    sequence_step = 0;
    step_timer = 0;
    
    executeStandUpStep();
    
    return true;
}

void Kinematic::stopSequence() {
    if (sequence_running) {
        ESP_LOGI(TAG, "Stopping sequence at step %d", sequence_step);
        sequence_running = false;
        sequence_step = 0;
        step_timer = 0;
    }
}
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

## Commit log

2025-10-11 chore: add empty pcb files
    [Bobot_2_Amethyst.kicad_pcb, Bobot_2_Amethyst.kicad_sch]
2025-10-11 pcb: add basic elements to esp32 and buttons pcbs
    [Bobot_2_Amethyst.kicad_pcb, Bobot_2_Amethyst.kicad_sch]
2025-10-12 pcb: update buttons alignment
    [Bobot_2_Amethyst.kicad_pcb]
2025-12-18 docs: add technical specifications for screwdriver case, esp32, display, batteries and battery management module
2025-12-19 docs: update battery management module pinout
2025-12-21 pcb: reorganize kicad project and add basic schematics
    [BMSBoard.kicad_sch, Bobot_2_Amethyst.kicad_pcb, ButtonsBoard.kicad_sch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]
2025-12-21 pcb: add battery and thermistor connection schematics
    [BMSBoard.kicad_sch, Bobot_2_Amethyst.kicad_pcb, MainBoard.kicad_sch]
2025-12-25 pcb: complete BMS board schematic
    [BMSBoard.kicad_sch, MainBoard.kicad_sch]
2025-12-25 docs: update shortcut component list to include BMS required components
2025-12-25 pcb: add buttons board schematics except I2C address
    [BMSBoard.kicad_sch, Bobot_2_Amethyst.kicad_pcb, ButtonsBoard.kicad_sch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]
2025-12-25 docs: add components for buttons board into shortcut components list, fix mistakes and fill out some values
2025-12-27 pcb: add touch sensor board
    [BMSBoard.kicad_sch, Bobot_2_Amethyst.kicad_pcb, Bobot_2_Amethyst.kicad_sch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]
2025-12-28 docs: add documentation for MCP23017 io expander and buttons connection
2025-12-30 fix: change function initializing display driver for right addressing
    [main.cpp]
2025-12-30 feat: add basic working example for display and buttons
2026-01-07 fix: add git submodules as regualr directories with modified code
    [board.dxf, clock.dxf, clock_2.dxf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]
2026-01-10 chore: update access permissions
    [BMSBoard.kicad_sch, Bobot_2_Amethyst.kicad_pcb, Bobot_2_Amethyst.kicad_sch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]
2026-01-14 fix: fix incorrect frame export order and inversion of pixels
2026-01-14 feat: add debug UI switching between animations on UI press
2026-01-14 feat: add animation imu-based offset
2026-01-14 feat: change image loading implementation and UI button timing
2026-01-18 feat: add buzzer controll
    [buzzer.cpp, main.cpp]
2026-02-04 feat: add legs control mode
2026-02-06 docs: add design_specs for legs editor
2026-02-06 feat: add gui skeleton for legs editor
2026-02-06 feat: add legs editor gui forwarding into browser
2026-02-06 fix: legs rendering
2026-02-07 refactor: remove i2c bus scanner
2026-02-08 fix: change servo channel order
    [main.cpp, servo_driver.cpp]
2026-02-10 feat: add working stand up and housing sequences for legs
